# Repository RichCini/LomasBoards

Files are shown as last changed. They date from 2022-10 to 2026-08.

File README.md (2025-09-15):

# LomasBoards
Small repository of files/data related to Lomas Data Products S-100 boards. I have
a particular interest in the Color Magic video board as it seems to have been
supported by the Seattle Gazelle that I own. 

## Color Magic Redux 
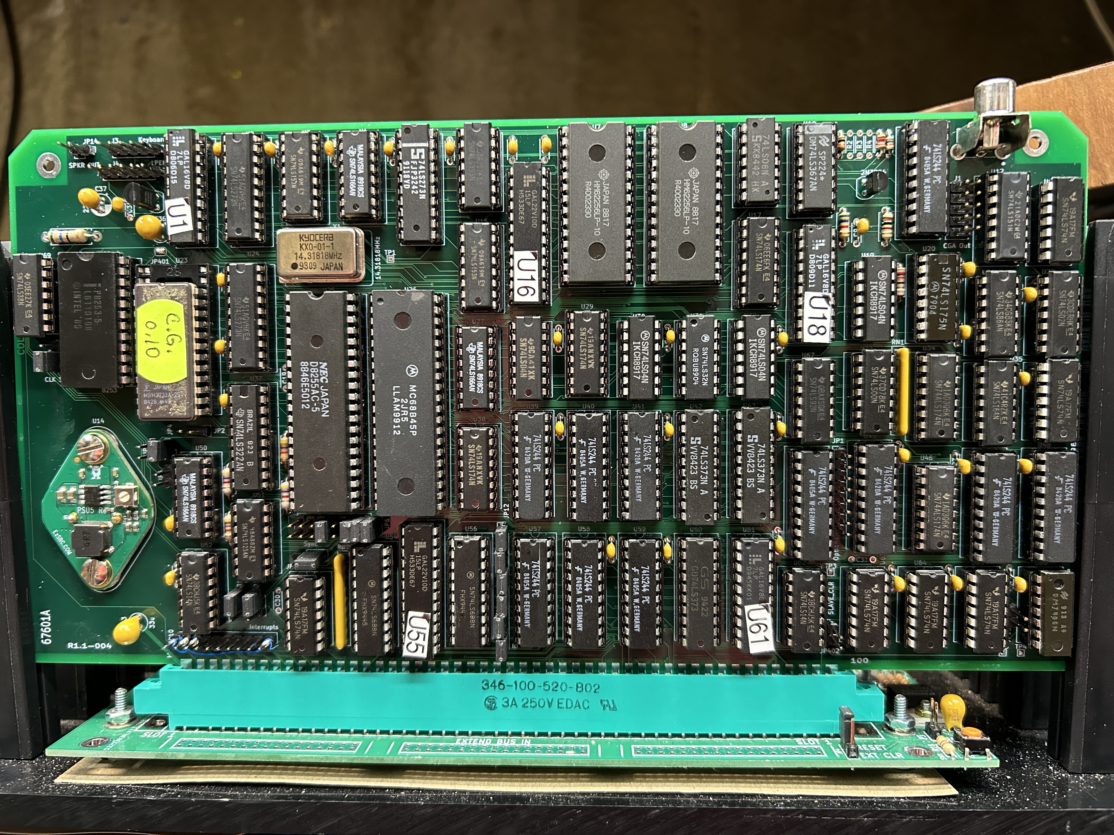
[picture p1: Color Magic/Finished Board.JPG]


### Status - version 1.1-005 / Version 006 In Development
1.1-005 is the release version, although in the process of debugging CGA Mode 6
(used for Windows 1.04 and Sim City) I discovered that the RAM chip selects are
improperly connected to MA13. It is OK to run the board without the following change if
only text or low-resolution modes are used.

To make the correction on existing 1.1-005 boards, it requires lifting pin 20
of each SRAM (CS*) and connecting it to ground, and lifting pin 26 (A13) and
connecting to MA13 (pin 20 of the socket). I did this with some 30AWG wire-
wrapping wire soldered to the tops of the pins in question.

There is also a revised versions of the U18 and U55 PALs that's recommended for all users.
Again, the update to U18 is related to discoveries made in debugging Mode 6, while the
update to U55 is related to a discovery by Patrick Linstruth that the MS-DOS RTC was
running fast. The 8253 timer was not being initialized properly due to a missing term
in one of the equations.

### Board Notes
Regarding CGA Mode 6, with the above change, it now works, although it shows a
screen artifact, the same as the original board. In this mode, there is a vertical
black stripe along the left side of the screen image which would indicate there's
a timing issue in the horizontal blanking (i.e., video out is being enabled 
one-half character time too early, before the load/shift from the character generator
is ready for the first set of dots, and then disabled the same half-character early
at the end of the video line.) As this exists in the original board, its a mode that
may have not been tested because so few software packages at the time used that mode.

The 5V voltage regulator is a TO-3 switching replacement from EzSBC. To preserve the
footprint and schematic symbol, it's shown as an LM7805K.

The speaker connection is like the PC -- simple 4-8 ohm speaker.

The keyboard is a standard PC 5150 type. If you want to use a PS/2-style 
keyboard, you need to use an AT2XT keyboard converter. I got mine on eBay
and it has both PS/2 and AT inputs and an XT (DIN-5) output. J3 is the
keyboard interface connector. You will need to build a small dongle cable 
with a DIN-5F on one end and a 1x5 0.1" pin header connector on the other.
The AT2XT adapter would then connect to this cable. The PC keyboard pinout
is available on the Internet.

Regarding video, the output is standard RGBI/CGA in addition to B&W composite. 
The RGBI interface cable is a standard 2x5 IDC to a DE9F. To use with a modern
HDMI monitor, you need to use an RGB2HDMI adapter like the one from TexElec
(https://texelec.com/product/rgbtohdmi-ttl/?highlight=hdmi). This one works
very well and can be used for more than just this setup.

Regarding memory devices, the design seems to be very sensitive to device speeds
(i.e. EPROM and SRAM). The character generator EPROM is a D2732A which is a 250ns
device. The original SRAM are stacked 6264-15 (150ns) chips which I replaced with
62256-10 (100ns) devices with some adjustments to the circuit. I temporarily used
55ns chips, and those resulted in screen artifacts. PAL device speeds are either
7ns or 15ns depending on the device.

## Thunder 186 Redux 
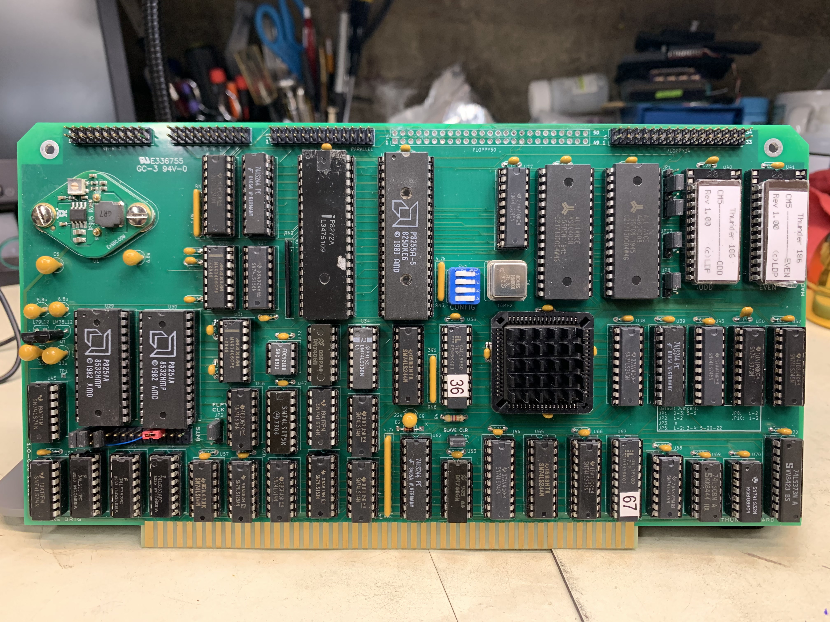
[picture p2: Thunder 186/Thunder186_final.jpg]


### Status - version 1.0-006 FINAL
Three minor changes: the serial headers were changed back to the 2x10 used on the prototype
(which then requires using a DB25F cable), consistent with the original; corrected the
footprint on C9 to a polarized tantalum; final change was to rotate the CPU 180 degrees
to have the chip legend oriented properly.

As with the ColorMagic, the 5V voltage regulator is a TO-3 switching replacement from EzSBC. 
To preserve the footprint and schematic symbol, it's shown as an LM7805K.

### Board Notes
The serial section seems to be sensivite to the voltage levels used on the interface of the
peripherals connected to it. This became evident when trying the old Move-IT file transfer
program. My go-to serial-USB dongle wasn't driving the handshaking lines to conforming
voltages. After changing USB interfaces, it worked. Original interfaces, like on a DOS
laptop I keep around for such purposes, work fine.

Regarding DOS versions, I run PC/DOS rather than MS-DOS. Versions 3.0, 3.1, and 3.3 work.
I have a single 360k MS-DOS 3.1 disk image which is posted. MS-DOS 2.1 disks are 
also in the archive, but appear to rely on direct calls into the monitor in order to
boot (non-standard MS-DOS boot sector) and are 320k in size (8 sectors).

The I/O ports (serial and parallel) are at non-standard, non-PC-compatible addresses, so
any software that uses them either has to (1) allow for defining custom ports, (2) read
the BIOS data area in order to get the right port number, or (3) rely solely on BIOS
calls to access the hardware. 

Similar to the serial port, the parallel port seems sensitive to what it's connected
to. I used LPT-Capture (https://github.com/bkw777/LPT_Capture) which works with an old
DOS laptop but will not work with this parallel port. I have gotten it working using a
Practical Peripherals Serial/Parallel converter/buffer. Although I haven't tested it,
it's possible the LPT-Capture would work on that port.

In the process of debugging Mode 6 video (mentioned above) some users reported that depending
on the S-100 backplane used, a pull-up resistor might be needed on PRDY (pin 72). There is a note
on the schematic about this, but the original design did not include one. RN2 pin 8 (1.0k 
resistor array) can be connected to pin 72 (on the rear) of the S-100 edge connector with a piece
of wirewrap wire.

### Status - version 1.0-005 Working
Works! PC-DOS 3 reports 256k of RAM which is correct. 

There is one errata. Capacitor C9 in the reset circuit should be 22uF/16v polarized; it
is misdrawn on the original schematic. A regular tantalum fits fine in this space. The
original board uses a 10v tantalum.

## LomasSCSI 

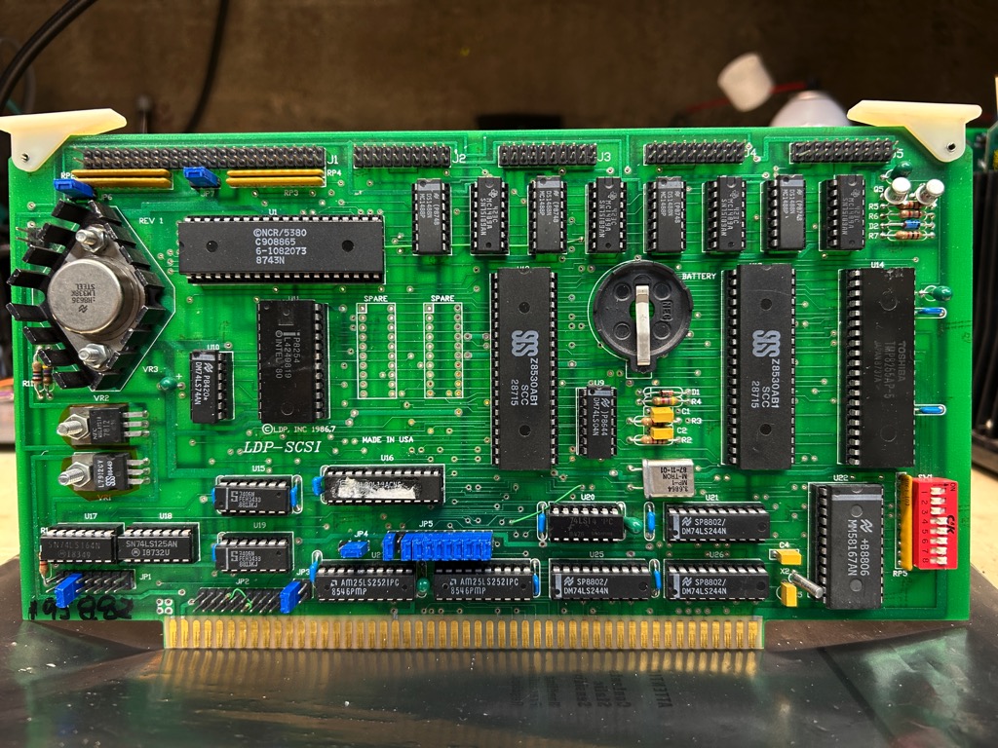
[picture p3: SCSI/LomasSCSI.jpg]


### Status --
The board is about 85% redrawn in KiCAD. Since no printed schematics are known to exist, this is
being done by the "continuity tester" method -- ohming out every connection on the board. Slow
going at best. This method did allow me to determine the PAL pin usage, though.

The board contains one PAL, U16 (a 20L10), used as an address decoder. The PAL has been reversed and the
equations tested against the original by burning another PAL, but without a working test setup for
the original board, confirming that the equations are 100% correct is difficult. From probing,
I do believe that they are correct, though. So, more to come on this.

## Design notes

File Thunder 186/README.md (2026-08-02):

# Thunder 186
Small repository of files/data related to Lomas Data Products Thunder 186 as well
as the KiCAD design files for my replica.

## Disk Images
From a Facebook purchase, I was able to obtain original MS-DOS 2.11 and
Concurrent CP/M-86 distribution disks. The MS-DOS disks were intact and
readable but they will not mount on any normal system because the format
of track 0 is unique to Lomas. Patching it to make it readable in a
normal machine makes it unusable on the T186 (you need to overwrite
sector 0 with a standard MS-DOS boot sector).

Regarding the Concurrent CP/M-86 disks, disk 1 is not readable due to a
destroyed directory. Disks 2 and 3 are fine. Pete Higgins did extract 
the files from each disk and those are posted. Online AI tools did
grind away at the image and repaired it enough, but some of the programs
need to be replaced, and it's still not bootable. Progress...

The PCDOS-winslow disk is a PC/DOS bootable image that contains
Windows 1.0 configured for no mouse and a CGA monitor. It will work
with the ColorMagic, but the user experience is bad without a mouse.

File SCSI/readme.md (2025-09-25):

Unfortunately not a lot is known about this board from Lomas. It's a SCSI controller with two serial ports and an RTC.
Schematics are not known to exist, and I have not been able to locate a manual anywhere. The onboard ROM has been 
archived, but it contains a PAL which is more difficult to de-logic without a schematic. Using the DuPAL tool and
some manual logic texting, I think the equations posted are very close to actual, but without a working setup
(in process), it's hard to test.

The schematics, board plot, and design files are as close to actual that I can get without seeing an original
schematic. I ohmed-out the entire board, so I'm pretty confident its right, but still...

I made one component substitution which saved three chips -- I used higher-density MAX1406 level shifters rather
than the usual MC1488/MC1489. Other than that, it's all the same.

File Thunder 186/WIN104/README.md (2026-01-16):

# Notes on Windows 1.04 on Lomas Boards

## Introduction
The Thunder 186 and its BIOS are kind-of PC-Compatible in the way that
the Tandy 2000 was PC-Compatible. So long as software uses either MS-DOS
INT21h calls or direct BIOS calls, it should work fine. Anything else
would require writing custom hardware interfaces because device port 
addresses are at non-standard locations.

The Tandy 2000 was able to run Windows 1.04 using OEM drivers written
by Tandy (or someone contracted by Tandy). Since the Color Magic is
CGA-compatible, the other hardware items which would need custom
drivers would be for the serial and parallel ports, and the "system"
itself (which means floppy drive configuration and system timers).

No copies of the Tandy driver sources are known to exist, but the 
pre-install disk does exist. No copies of an "OEM Adaptation Kit"
are known to exist for Windows 1, but there is one for Windows 2
(which unfortunately is different enough). So, I've attempted to
back-port the published sources for COMM and SYSTEM from Windows 2.03
to something that would work for Windows 1, using a decompilation of 
the Tandy drivers as a guide.

## Status
As of now, I've back-ported SYSTEM and at least it doesn't crash. I'm
not sure if it's right, but no crashing is good.

I'm in the process of back-porting of COMM but that's much tougher
because the interrupt system in the Thunder 186 is all different
(and even different from the Tandy 2000). I'd love to locate a
"null" COMM driver and use that for now.

Windows will load and run using the "slow boot" configuration
and the CGA video driver (DRV, GRB, and LGO files) and it does work. 

Windows 1 and 2 used a monolithic file containing all of the drivers
combined in one file to improve loading performance. The modern analog 
would be the WIN386 file in Windows 3.1 where all of the VXDs are combined. 
The slow boot configuration is a special debug mode using the debug
kernel and the individual drivers for COMM, DISPLAY, KEYBOARD, MSDOS, MOUSE, 
and SOUND. It facilitated debugging and swapping drivers for testing.

There is a screen anomaly where it appears that the screen is shifted right 
by half a character cell. It's the same with the original Color Magic and the
one I re-created, so it's not a "board thing" but something in the video
subsystem and/or BIOS where the blanking signal is delayed slightly too long. 
I played around with delays in the video circuit but I was never able to get it
to be perfect, so I just left it. It's not clear whether Lomas envisioned
being able to run Windows, so they either never tested, or didn't care to
fix it.

Also, there is no mouse input. Mouse input relies on either standard
serial ports or an InPort bus mouse, neither of which is straightforward
to implement on a Lomas system because of the interrupt system. It would
require a redesign of the interrupt system to use external 8259 PICs 
instead of the PIC internal to the 80186. On the up side, keyboard
shortcuts work.

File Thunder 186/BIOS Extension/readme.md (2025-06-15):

Note that due to the age of the code, a relatively primative version of Microsoft MACRO assembler is needed.
The build files came from the zip file located as a link at https://www.os2museum.com/wp/dos-2-11-from-scratch/

MASM and EXE2BIN are dated 2/1/83 and LINK is dated 1/6/83.

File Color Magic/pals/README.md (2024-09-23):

# Reading the PALs
Although I'm keeling the summary below, it turned out that the PALs were not able to
be decoded properly using the method below. It required the assistance of someone
with more robust hardware and an intimate knowledge of PAL equation writing. He was
able to reverse the PALs and produce working files. I plan on trying to replicate
his setup at some point, but that's to come.

## DuPAL board
The basis of reading the PALs is a project called DuPAL (https://github.com/DuPAL-PAL-DUmper)
which has several associated Java-based tools to read the PAL, analyze the results,
and do equation reductions. The instructions aren't as fulsome as they could be, 
so here are some notes to hopefully make it easier for others. Also helpful is the site
https://proghq.org/wiki/index.php/DuPAL which runs through compiling some of the Java
code.

Largely no issues getting the board manufactured. Rather than using the existing gerbers,
I loaded the design into KiCAD and tweaked a few components and placements to fit my
liking. I moved the overlapped bypass capacitors and changed the foortprints for the
DE9M, power switch, and the coaxial power jack to match parts I already had in-stock.

## DuPAL Firmware
The Atmel ATMega328 can be programmed in-circuit using the ISP header (for loading
the Optiboot bootloader) or out-of-circuit using any number of methods. I used a
USBtinyISP programmer from Adafruit attached to the ISP header. First, download Optiboot, 
compile it, and the program it into the ATMega:

  make atmega328 AVR_FREQ=20000000L LED_START_FLASHES=8 BAUD_RATE=57600

  avrdude  -c avrtiny -P /dev/ttyUSB0 -p atmega328p -e -u -U efuse:w:0xFD:m \
  -U hfuse:w:0xDE:m -U lfuse:w:0xFF:m -U flash:w:optiboot_atmega328.hex

Connect the host PC to the serial port on the DuPAL, compile and upload the firmware:

  make

  make program

## DuPAL Analyze
The different software packages require different versions of Java. Analyze uses Java 8.
Make sure that "maven" is installed: 

  sudo apt-get install maven

Then, change to the directory with the source code and compile it:

  mvn compile

  sudo mvn install

The ./target folder contains the compiled JAR file. Run that:

  java -jar ./target/dupal-analyzer-0.1.4-jar-with-dependencies.jar /dev/ttyUSB0 16L8 out.json

It will first analyze the GAL to detect the byte mask. Then, re-run with the detected mask (where "xx"
is the mask number provided):

  java -jar ./target/dupal-analyzer-0.1.4-jar-with-dependencies.jar /dev/ttyUSB0 16L8 out.json xx

## DuPAL Peeper
This program requires compiling using Java 11, so you need to switch to that before
compiling.

Using in on-line mode:

  java -jar ./target/dupal-peeper-0.0.1-jar-with-dependencies.jar --serial=/dev/ttyUSB0 --pal=16L8

Using in off-line mode:

  java -jar ./target/dupal-peeper-0.0.1-jar-with-dependencies.jar --dump=/path/to/dump.json

## DuPAL Espresso Converter
This program requires compiling using Java 11, so you need to switch to that before
compiling. I have not played with this yet, but here's the command line:

  java -jar espresso_converter.jar <input_file> <output_file> [single output table] [use only source FIOs Y|N]

  java -jar ./target/espresso-converter-0.0.3-jar-with-dependencies.jar

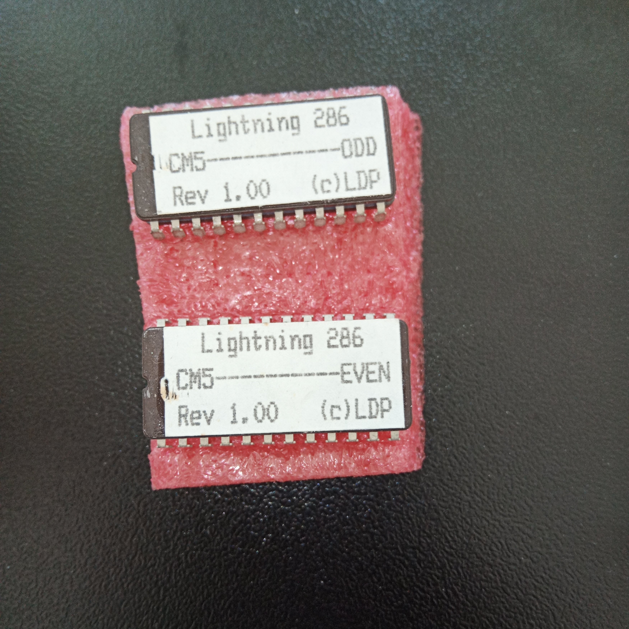
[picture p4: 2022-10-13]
ROMs.jpg

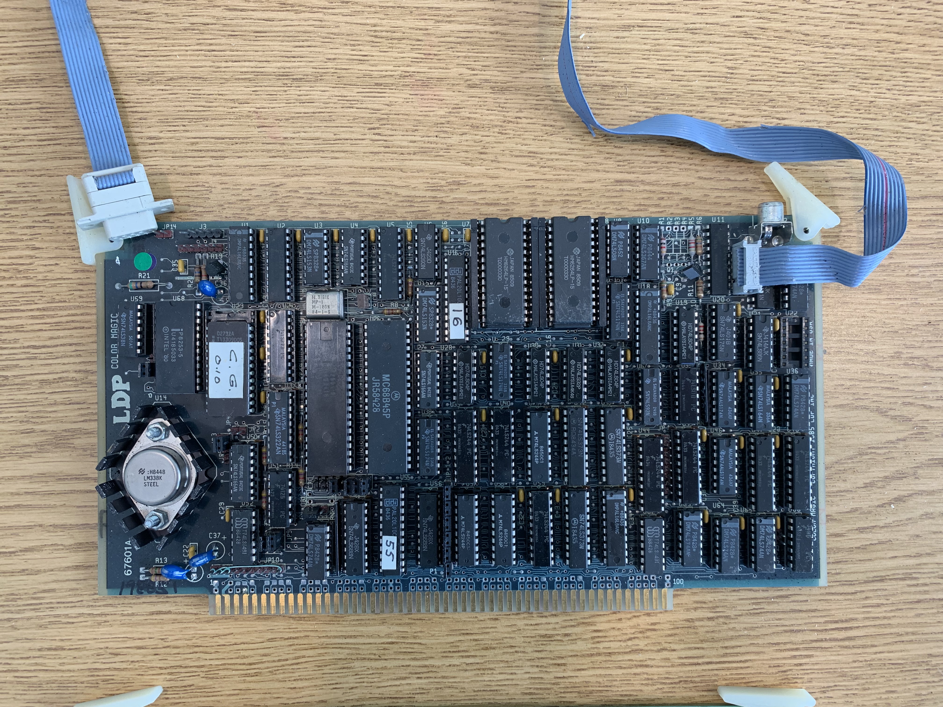
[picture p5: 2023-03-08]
Color Magic/Lomas_ColorMagic_Video.jpg

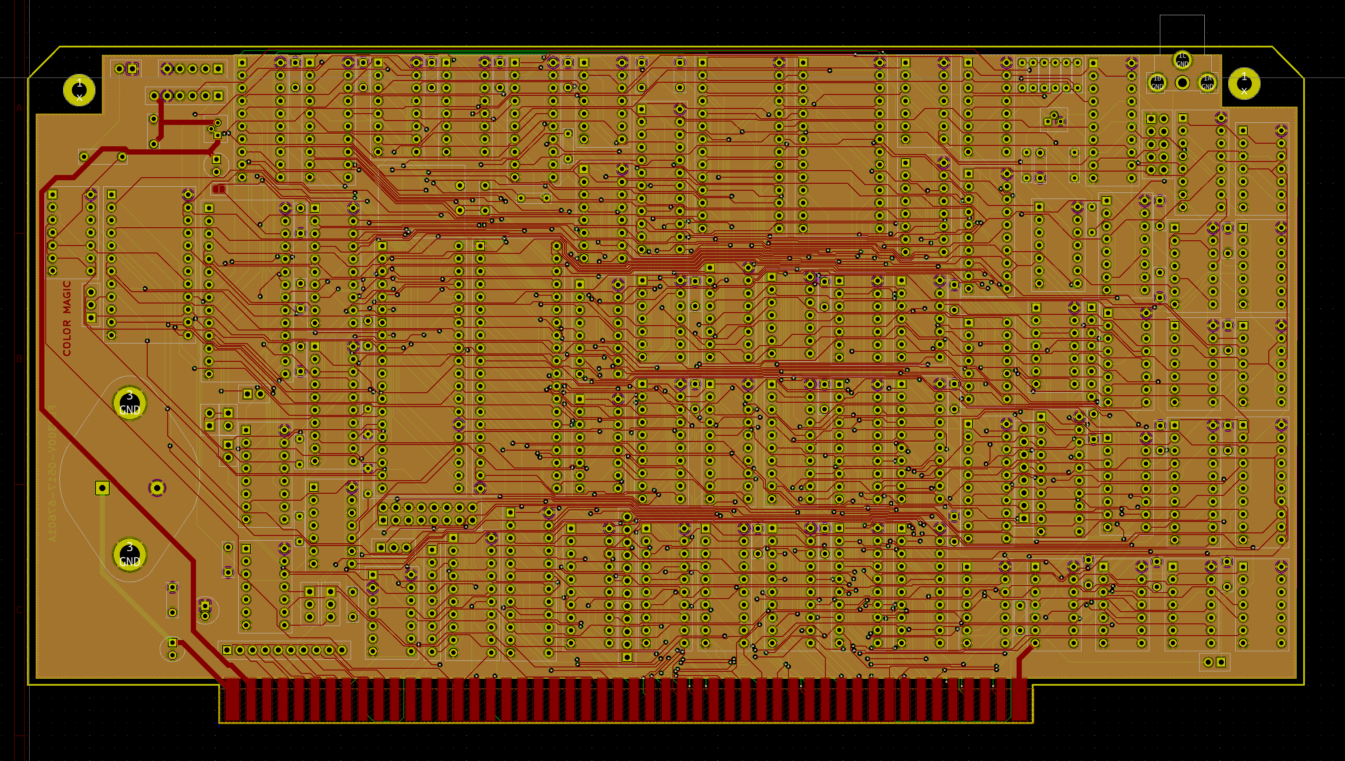
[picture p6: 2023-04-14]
Color Magic/Screen Shot 2023-04-14 at 8.41.56 AM.png

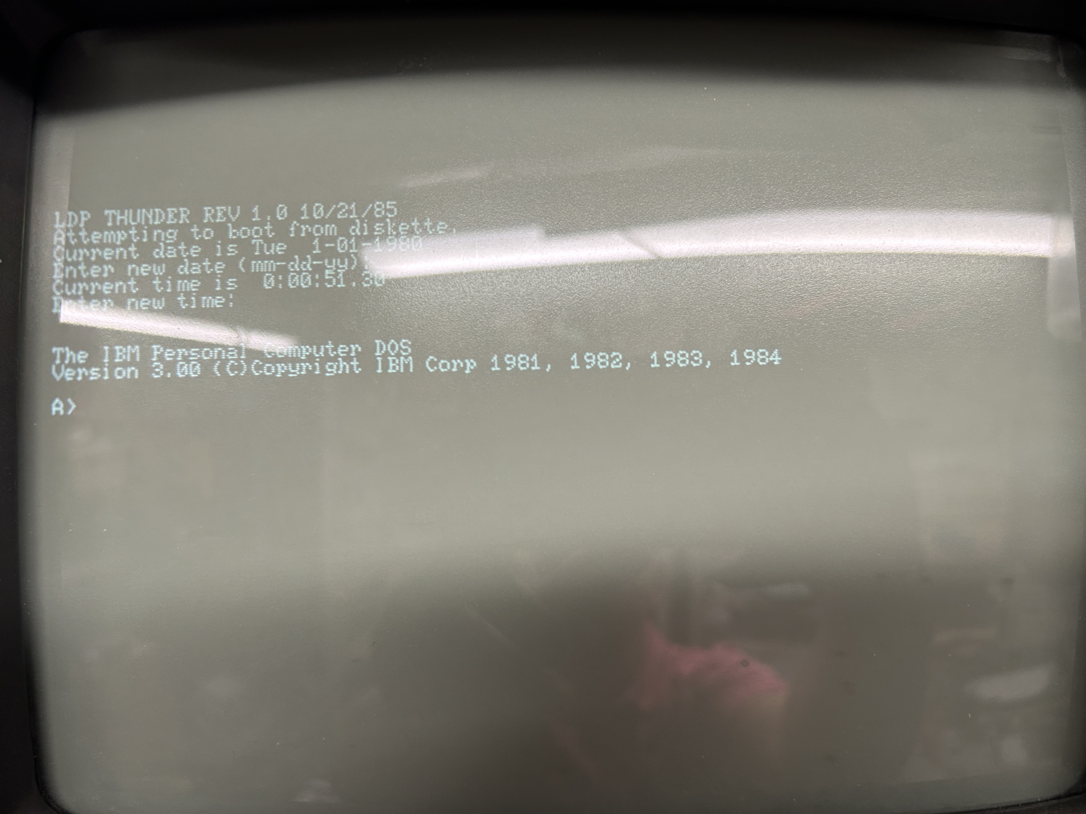
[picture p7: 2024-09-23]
Color Magic/LCM_first_working.JPG

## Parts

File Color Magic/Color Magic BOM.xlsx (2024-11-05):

Schematic Part # | Description | Total quantity of this part | Part Number | Source
C1, C2, C3, C4, C5, C6, C7, C9, C10, C11, C12, C14, C15, C16, C17, C20, C21, C18, C19, C20, C21, C22, C23, C24, C25, C26, C27, C28, C29, C30, C31,C32, C33, C34, C35, C38, C39, C40 | 0.1 uF, 50 Volt, Monolithic, X7R, Radial | 38 | 544921 | Jameco
C13, C36 | 33 uF, 25 Volt, 10%, Radial Tantalum | 2 | 33785 | Jameco
C19, C30, C31 | 47pF, 50V Monolithic Radial 2.5mm lead | 3 | 81-RDE5C1H470J0M1H3A | Mouser
C37 | 22uF, 35V, 10%, Radial Tantalum | 1 | 2040196 | Jameco
J1 (RGBI video out) | 5x2 Position, Unshrouded Header 2.54mm Solder, Straight | 1 |  | Jameco
J2 (Composite video out) | RCA jack, right angle PC mount | 1 | 220564 | Jameco
J3 (Keyboard) | 5 Position, Unshrouded Header 2.54mm Solder Straight | 1 |  | Jameco
J4 (Light pen) | 6 Position, Unshrouded Header 2.54mm Solder Straight | 1 |  | Jameco
JP2, JP3, JP4, JP5, JP14, JP15, JP402 | 2 Position, Unshrouded Header 2.54mm Solder Straight | 7 |  | Jameco
JP6 | 8x2 Position, Unshrouded Header 2.54mm Solder, Straight | 1 |  | Jameco
JP7, JP8, JP9. JP13 | 3 Position, Unshrouded Header 2.54mm Solder Straight | 4 |  | Jameco
JP10 | 10 Position, Unshrouded Header 2.54mm Solder Straight | 1 |  | Jameco
JP12 | 12 Position, Unshrouded Header 2.54mm Solder Straight | 1 |  | Jameco
JP401 | solder bridge
U1 | GAL16V8D 7LP or 7LPN | 20 | GAL16V8D 7LPN | utsource.net
U2 | 74LS273 | 20 | 595-SN74LS273N | Mouser
U3 | 74LS153 | 16 | 595-SN74LS153N | Mouser
U4 | 74LS166 | 16 | 595-SN74LS166AN (https://www.mouser.ca/ProductDetail/595-SN74LS166AN) | Mouser
U5 | 74LS273 | 20 | 595-SN74LS273N | Mouser
U6 | 74LS393 | 14 | 595-SN74LS393N | Mouser
U7 | HM62256LP-10 | 28 | HM62256LP-10 | utsource.net
U8 | HM62256LP-10 | 28 | HM62256LP-10 | utsource.net
U9 | 74LS08 | 14 | 595-SN74LS08N (https://www.mouser.ca/ProductDetail/595-SN74LS08N) | Mouser
U10 | 74LS367 | 16 | 595-SN74LS367AN | Mouser
U11 | 74LS244 | 20 | 595-SN74LS244N | Mouser
U12 | 74LS151 | 16 | 595-SN74LS151N | Mouser
U13 | 74LS74 | 14 | 595-SN74LS74AN (https://www.mouser.ca/ProductDetail/595-SN74LS74AN) | Mouser
U14 | EzSBC PSU5 5V switching regulator |  | PSU5 | ezsbc.shop
U15 | 74LS153 | 16 | 595-SN74LS153N (https://www.mouser.ca/ProductDetail/595-SN74LS153N) | Mouser
U16 | GAL22V10D 15LP | 24 | GAL22V10D 15LP | utsource.net
U17 | 74LS174 | 16 | 595-SN74LS174N (https://www.mouser.ca/ProductDetail/595-SN74LS174N) | Mouser
U18 | GAL16V8D 7LP or 7LPN | 20 | GAL16V8D 7LPN | utsource.net
U19 | 74LS04 | 14 | 595-SN74LS04N (https://www.mouser.ca/ProductDetail/595-SN74LS04N) | Mouser
U20 | 74LS175 | 16 | 595-SN74LS175N | Mouser
U21 | 74LS86 | 14 | 595-SN74LS86AN | Mouser
U22 | 74LS02 | 14 | 595-SN74LS02N | Mouser
U23 | Fujitsu MBM2732A-25 EPROM | 28 | MBM2732A-25 | utsource.net
U24 | 74LS273 | 20 | 595-SN74LS273N | Mouser
U25 | 8255AC-5 peripheral interface | 40 | 8255AC-5 | utsource.net
U26 | MC68B45P display controller | 40 | MC68B45P | utsource.net
U27 | 74LS166 | 16 | 595-SN74LS166AN | Mouser
U28 | 74LS04 | 14 | 595-SN74LS04N (https://www.mouser.ca/ProductDetail/595-SN74LS04N) | Mouser
U29 | 74LS174 | 16 | 595-SN74LS174N (https://www.mouser.ca/ProductDetail/595-SN74LS174N) | Mouser
U30 | 74LS04 | 14 | 595-SN74LS04N (https://www.mouser.ca/ProductDetail/595-SN74LS04N) | Mouser
U31 | 74LS32 | 14 | 595-SN74LS32N | Mouser
U32 | 74LS04 | 14 | 595-SN74LS04N (https://www.mouser.ca/ProductDetail/595-SN74LS04N) | Mouser
U33 | 74LS00 | 14 | 595-SN74LS00N (https://www.mouser.ca/ProductDetail/595-SN74LS00N) | Mouser
U34 | 74ALS174 | 16 | 595-SN74ALS174N (https://www.mouser.ca/ProductDetail/595-SN74LS174N) | Mouser
U35 | 74LS164 | 14 | 595-SN74LS164N (https://www.mouser.ca/ProductDetail/595-SN74LS164N) | Mouser
U36 | 74LS74 | 14 | 595-SN74LS74AN (https://www.mouser.ca/ProductDetail/595-SN74LS74AN) | Mouser
U37 | 74LS322 | 20 | SN74LS322AN | utsource.net
U38 | 74LS174 | 16 | 595-SN74LS174N | Mouser
U39 | 74LS244 | 20 | 595-SN74LS244N | Mouser
U40 | 74LS244 | 20 | 595-SN74LS244N | Mouser
U41 | 74LS244 | 20 | 595-SN74LS244N | Mouser
U42 | 74LS373 | 20 | 595-SN74LS373N | Mouser
U43 | 74LS373 | 20 | 595-SN74LS373N | Mouser
U44 | 74LS244 | 20 | 595-SN74LS244N | Mouser
U45 | 74LS244 | 20 | 595-SN74LS244N | Mouser
U46 | 74ALS174 | 16 | 595-SN74ALS174N | Mouser
U47 | 74LS244 | 20 | 595-SN74LS244N | Mouser
U48 | 74LS244 | 20 | 595-SN74LS244N | Mouser
U49 | LM78L12 positive 12V .1A regulator |  | 595-UA78L12ACLPR | Mouser
U50 | 74LS166 | 16 | 595-SN74LS166AN (https://www.mouser.ca/ProductDetail/595-SN74LS166AN) | Mouser
U51 | 74125 or 74LS125 | 14 | SN74125N | utsource.net (for 74125)
U52 | 74LS14 | 14 | 595-SN74LS14N (https://www.mouser.ca/ProductDetail/595-SN74LS14N) | Mouser
U53 | 74LS74 | 14 | 595-SN74LS74AN (https://www.mouser.ca/ProductDetail/595-SN74LS74AN) | Mouser
U54 | 74LS688 | 20 | 595-SN74LS688N | Mouser
U55 | GAL22V10D 15LP | 24 | GAL22V10D 15LP | utsource.net
U56 | 74LS688 | 20 | 595-SN74LS688N | Mouser
U57 | 74LS244 | 20 | 595-SN74LS244N | Mouser
U58 | 74LS244 | 20 | 595-SN74LS244N | Mouser
U59 | 74LS244 | 20 | 595-SN74LS244N | Mouser
U60 | 74LS373 | 20 | 595-SN74LS373N | Mouser
U61 | GAL16V8D 7LP or 7LPN | 20 | GAL16V8D 7LPN | utsource.net
U62 | 74LS14 | 14 | 595-SN74LS14N (https://www.mouser.ca/ProductDetail/595-SN74LS14N) | Mouser
U63 | 74LS74 | 14 | 595-SN74LS74AN (https://www.mouser.ca/ProductDetail/595-SN74LS74AN) | Mouser
U64 | 74LS74 | 14 | 595-SN74LS74AN (https://www.mouser.ca/ProductDetail/595-SN74LS74AN) | Mouser
U65 | 74LS74 | 14 | 595-SN74LS74AN (https://www.mouser.ca/ProductDetail/595-SN74LS74AN) | Mouser
U66 | 7406 or 74LS06 | 14 | DN7406N | utsource.net (or 7406)
U67 | 74LS92 | 14 | 595-SN74LS92N | Mouser
U68 | 8253-5 interval timer | 24 | P8253-5 | utsource.net
U69 | 74LS38 | 14 | 595-SN74LS38N (https://www.mouser.ca/ProductDetail/595-SN74LS38N) | Mouser
RN1 | 4.7K x 7 SIP (8 pin) | 1 | 652-4608X-1LF-4.7K | Mouser
RN2 | 4.7K x 8 SIP (9 pin) | 1 | 652-4609X-1LF-4.7K | Mouser
R1 | 1.0K ohm 1/4W (1/8 body size) | 1 | 594-5063JD1K000F | Mouser
R2 | Not populated | 0
R3 | Not populated | 0
R4 | Not populated | 0
R5 | 2.2K ohm 1/4W (1/8 body size) | 1 | 594-5063JD2K200F | Mouser
R6 | 5.6K ohm 1/4W (1/8 body size) | 1 | 594-5063JD5K600F | Mouser
R9 | 5.6K ohm 1/4W | 1 | 660-MF1/4LCT52R562J | Mouser
R10 | 22 ohm 1/4W | 1 | 660-MF1/4LCT52R220J | Mouser
R11 | 100 ohm 1/4W | 1 | 660-MF1/4LCT52R101J | Mouser
R14, R15, R16, R17 | 4.7K ohm 1/4W | 4 | 660-MF1/4LCT52R472J | Mouser
R21 | 56 ohm 1/2W | 1 | 756-MFR4-56RFI | Mouser
Q1 | 2N3904 | 1 | 38359 | Jameco
X1 | 14.31818MHZ oscillator | 1 | 520-TCF1431-X | Mouser
14 pin socket 0.3 wide |  | 23
16 oinsocket 0.3 wide |  | 13
20 pin socket 0.3 wide |  | 23
24 pin socket 0.3 wide |  | 2
24 socket 0.6 wide |  | 1
28 socket 0.6 wide |  | 3
40 socket 0.6 wide |  | 2
CGA monitor cable |  | 1 | Use standard IDC10 to DE9F
Keyboard cable |  | 1 | See board notes

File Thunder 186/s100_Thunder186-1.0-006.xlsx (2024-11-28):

Have? | Reference | Value | Qty | Part_Number | Footprint
 | C1,C2,C3 | 6.8u, 35v | 3 |  | Capacitor_THT:CP_Radial_Tantal_D4.5mm_P2.50mm
 | C4,C5,C10,C11,C12,C13,C14,C15,C16,C17,C18,C19,C20,C21,C22,C23,C24,C25,C26,C27,C28,C29,C30,C31,C32,C33,C34,C35,C36,C37,C38,C39,C40,C41,C42 | 0.1 uF, 50v | 35 |  | Capacitor_THT:C_Disc_D4.3mm_W1.9mm_P5.00mm
 | C6,C7,C8 | 33u, 25v | 3 |  | Capacitor_THT:CP_Radial_Tantal_D4.5mm_P2.50mm
 | C9 | 22u, 16v | 1 |  | Capacitor_THT:CP_Radial_Tantal_D4.5mm_P2.50mm
 | D2 | 1N4148 | 1 |  | Diode_THT:D_DO-35_SOD27_P7.62mm_Horizontal
 | J1, J2 | Header 2x5 | 2 |  | Connector_PinHeader_2.54mm:PinHeader_2x05_P2.54mm_Vertical
 | J3 | Header 2x13 | 1 |  | Connector_PinHeader_2.54mm:PinHeader_2x13_P2.54mm_Vertical
 | J4 | Header 2x17 | 1 |  | Connector_PinHeader_2.54mm:PinHeader_2x17_P2.54mm_Vertical
 | J5 | Header 2x25 | 1 |  | Connector_PinHeader_2.54mm:PinHeader_2x25_P2.54mm_Vertical
 | JP1 | Header 1x6 | 1 |  | Connector_PinHeader_2.54mm:PinHeader_1x06_P2.54mm_Vertical
 | JP2 | Header 1x3 | 1 |  | Connector_PinHeader_2.54mm:PinHeader_1x03_P2.54mm_Vertical
 | JP3 | Header 1x2 | 1 |  | Connector_PinHeader_2.54mm:PinHeader_1x02_P2.54mm_Vertical
 | JP5 | Header 2x14 | 1 |  | Connector_PinHeader_2.54mm:PinHeader_2x14_P2.54mm_Vertical
 | Q1 | LM78L12 | 1 |  | Package_TO_SOT_THT:TO-92L
 | Q2 | L79L12 | 1 |  | Package_TO_SOT_THT:TO-92L
 | R4 | 4.7kQ | 1 |  | Resistor_THT:R_Axial_DIN0207_L6.3mm_D2.5mm_P7.62mm_Horizontal
 | RN1 | 1.0k Rpack R5 SIP6 | 1
 | RN2 | 1.0k Rpack R9 SIP10 | 1
 | RN3 | 4.7k Rpack R4 SIP5 | 1
 | RN4 | 4.7k Rpack R9 SIP10 | 1
 | RN6 | 390 ohm Rpack R5 SIP6 | 1
 | SW1 | DIPSW_4 | 1 |  | Package_DIP:DIP-8_W7.62mm_Socket
 | U1 | LM7805K | 1 |  | Package_TO_SOT_THT:TO-3
 | U17 | 74LS156 | 1 |  | Package_DIP:DIP-16_W7.62mm_Socket
 | U2 | 74LS240 | 1 |  | Package_DIP:DIP-20_W7.62mm_Socket
 | U27,U38,U43,U52,U64 | 74LS245 | 5 |  | Package_DIP:DIP-20_W7.62mm_Socket
 | U28,U31 | MAX1406CPE+ | 2 |  | Package_DIP:DIP-16_W7.62mm_Socket
 | U29,U30 | 8251A | 2 |  | Package_DIP:DIP-28_W15.24mm_Socket
 | U3,U35,U39,U62,U65 | 74LS244 | 5 |  | Package_DIP:DIP-20_W7.62mm_Socket
 | U32 | FDC9216 | 1 |  | Package_DIP:DIP-8_W7.62mm_Socket
 | U33,U63 | 7406 | 2 |  | Package_DIP:DIP-14_W7.62mm_Socket
 | U34 | 74LS138 | 1 |  | Package_DIP:DIP-16_W7.62mm_Socket
 | U36,U67 | PAL16L8 | 2 |  | Package_DIP:DIP-20_W7.62mm_Socket
 | U37 | 80186 | 1 |  | Package_LCC:PLCC-68_THT-Socket
 | U4 | 8272A | 1 |  | Package_DIP:DIP-40_W15.24mm_Socket
 | U40,U41 | 27256 EPROM | 2 |  | Package_DIP:DIP-28_W15.24mm
 | U44,U51 | AS6C4008-55PCN | 2 |  | Package_DIP:DIP-32_W15.24mm
 | U45,U48,U53 | 74LS74 | 3 |  | Package_DIP:DIP-14_W7.62mm_Socket
 | U46 | 74LS06 | 1 |  | Package_DIP:DIP-14_W7.62mm_Socket
 | U47 | 74LS175 | 1 |  | Package_DIP:DIP-16_W7.62mm_Socket
 | U49,U59,U61 | 74LS14 | 3 |  | Package_DIP:DIP-14_W7.62mm_Socket
 | U5 | 82C55A | 1 |  | Package_DIP:DIP-40_W15.24mm
 | U50,U66,U72 | 74LS373 | 3 |  | Package_DIP:DIP-20_W7.62mm_Socket
 | U54,U55 | 74LS157 | 2 |  | Package_DIP:DIP-16_W7.62mm_Socket
 | U56 | 74LS161 | 1 |  | Package_DIP:DIP-16_W7.62mm_Socket
 | U57 | 74LS04 | 1 |  | Package_DIP:DIP-14_W7.62mm_Socket
 | U58 | 74LS125 | 1 |  | Package_DIP:DIP-14_W7.62mm_Socket
 | U60 | 74LS153 | 1 |  | Package_DIP:DIP-16_W7.62mm_Socket
 | U68 | 74LS375 | 1 |  | Package_DIP:DIP-16_W7.62mm_Socket
 | U69 | 74LS08 | 1 |  | Package_DIP:DIP-14_W7.62mm_Socket
 | U70 | 74LS32 | 1 |  | Package_DIP:DIP-14_W7.62mm_Socket
 | X1 | 16MHz Oscillator DIP-8 | 1 |  | Oscillator:Oscillator_DIP-8
 | Socket | DIP8-Osc | 1
 | Socket | DIP8 | 1
 | Socket | DIP14 | 13
 | Socket | DIP16 | 10
 | Socket | DIP20 | 16
 | Socket | DIP28 | 4
 | Socket | DIP32 | 2
 | Socket | DIP40 | 2
 | Socket | PLCC68 | 1

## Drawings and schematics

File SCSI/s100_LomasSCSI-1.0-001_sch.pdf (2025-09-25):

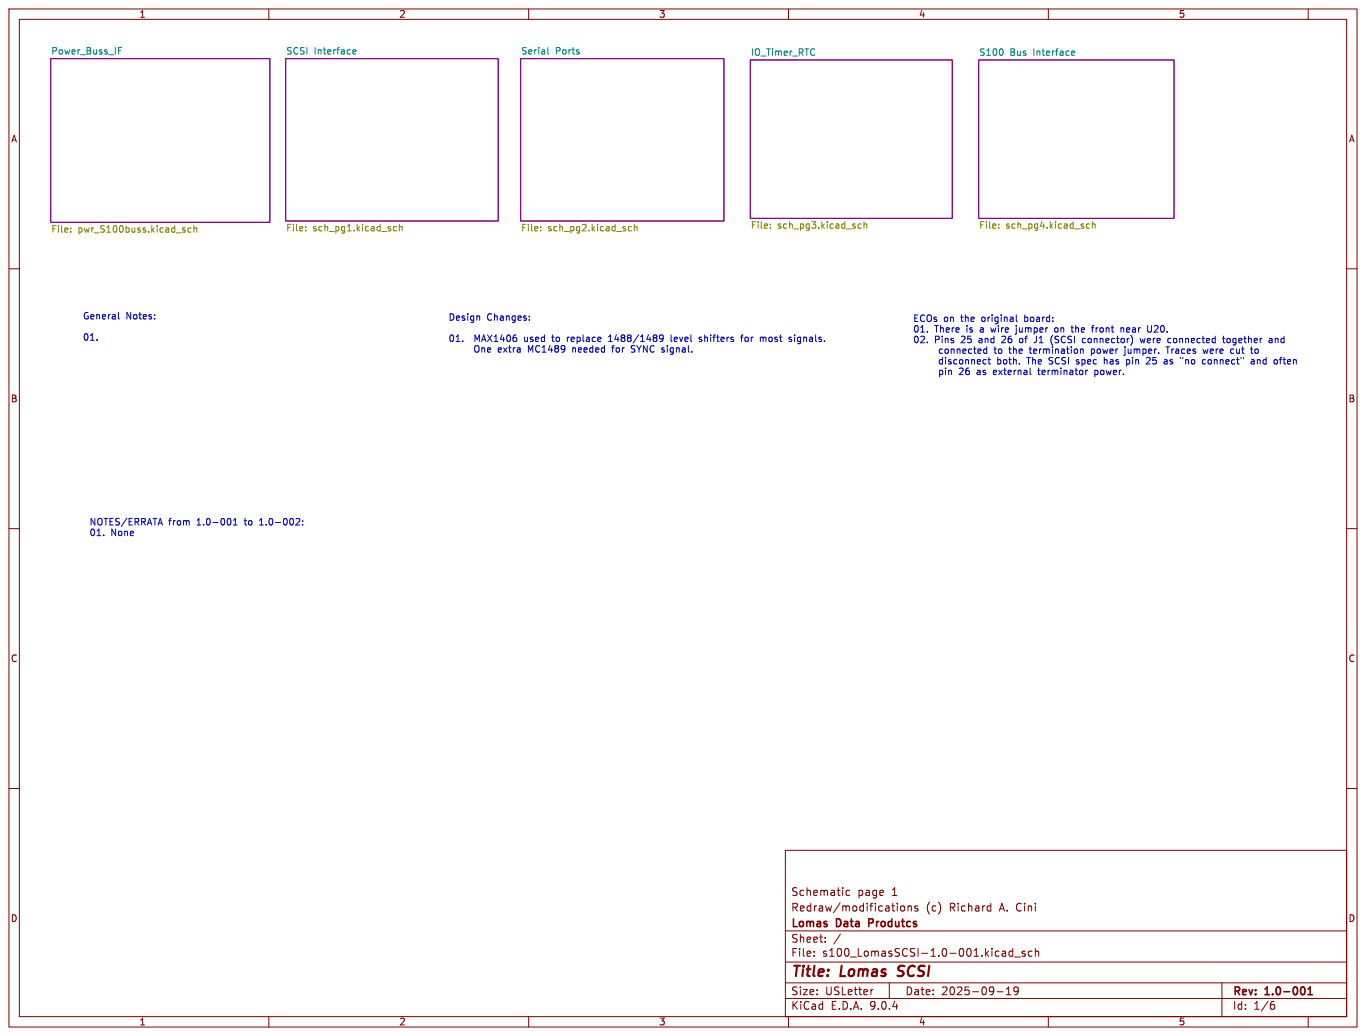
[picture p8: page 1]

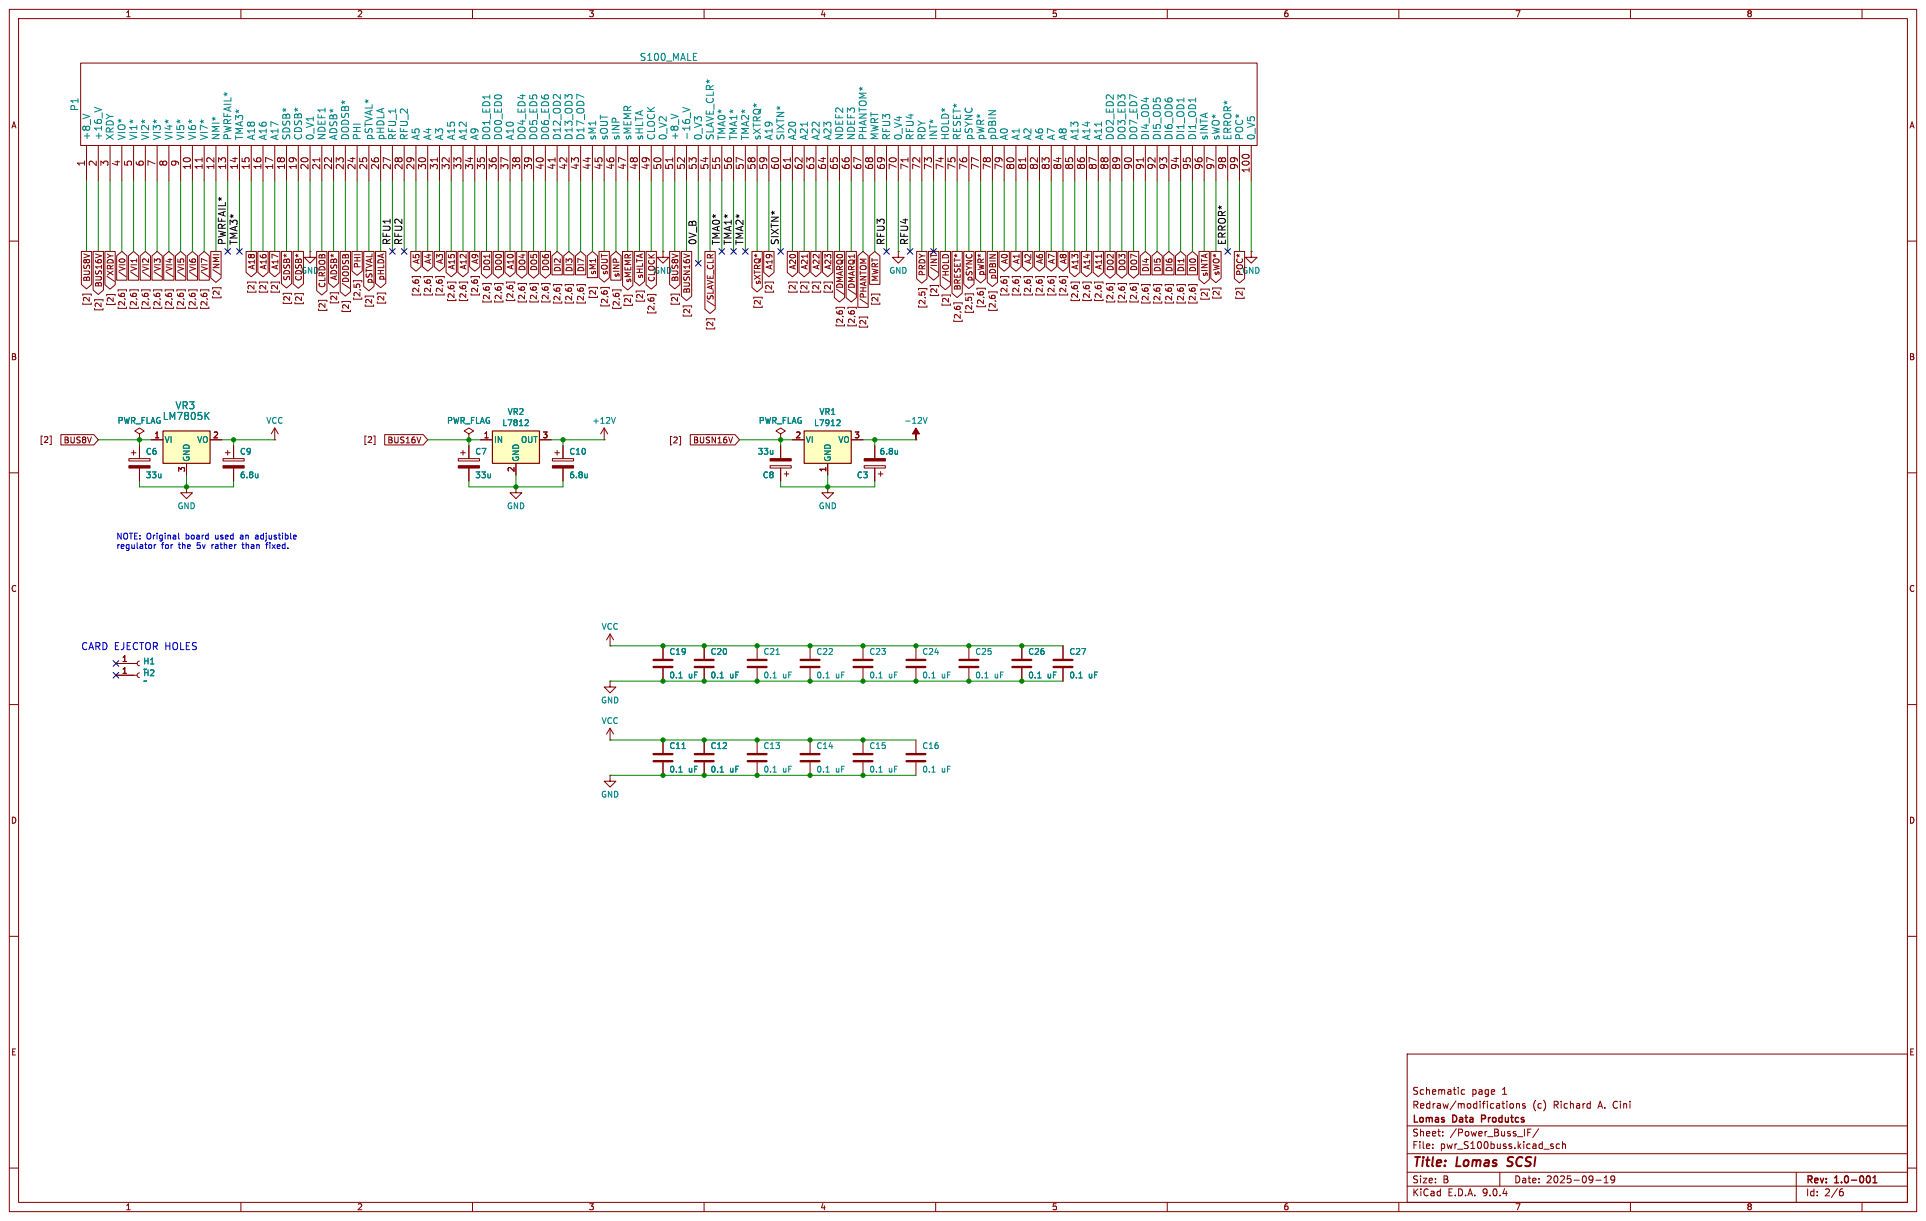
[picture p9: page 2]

3 VIO* 4 VI1* 5 VI2* 6 VI3* 7 VI4* 8 VI5* 9 VI6* 10 VI7* 11 NMI* 12 PWRFAIL* 13 TMA3* 14 A18 15 A16 16 A17 17 SDSB* 18 CDSB* 19 0_V1 20 NDEF1 21 ADSB* 22 DODSB* 23 PHI 24 pSTVAL* 25 pHDLA 26 RFU_1 27 RFU_2 28 A5 29 A4 30 A3 31 A15 32 A12 33 A9 34 DO1_ED1 35 DO0_ED0 36 A10 37 DO4_ED4 38 DO5_ED5 39 DO6_ED6 40 D12_OD2 41 D13_OD3 42 D17_OD7 43 sM1 44 sOUT 45 sINP 46 sMEMR 47 sHLTA 48 CLOCK 49 0_V2 50 +8_V 51 -16_V 52 0_V3 53 SLAVE_CLR* 54 TMA0* 55 TMA1* 56 TMA2* 57 sXTRQ* 58 A19 59 SIXTN* 60 A20 61 A21 62 A22 63 A23 64 NDEF2 65 NDEF3 66 PHANTOM* 67 MWRT 68 RFU3 69 0_V4 70 RFU4 71 RDY 72 INT* 73 HOLD* 74 RESET* 75 pSYNC 76 pWR* 77 pDBIN 78 A0 79 A1 80 A2 81 A6 82 A7 83 A8 84 A13 85 A14 86 A11 87 DO2_ED2 88 DO3_ED3 89 DO7_ED7 90 DI4_OD4 91 DI5_OD5 92 DI6_OD6 93 DI1_OD1 94 DI1_OD1 95 sINTA 96 sWO* 97 ERROR* 98 POC* 99 0_V5 100 P1

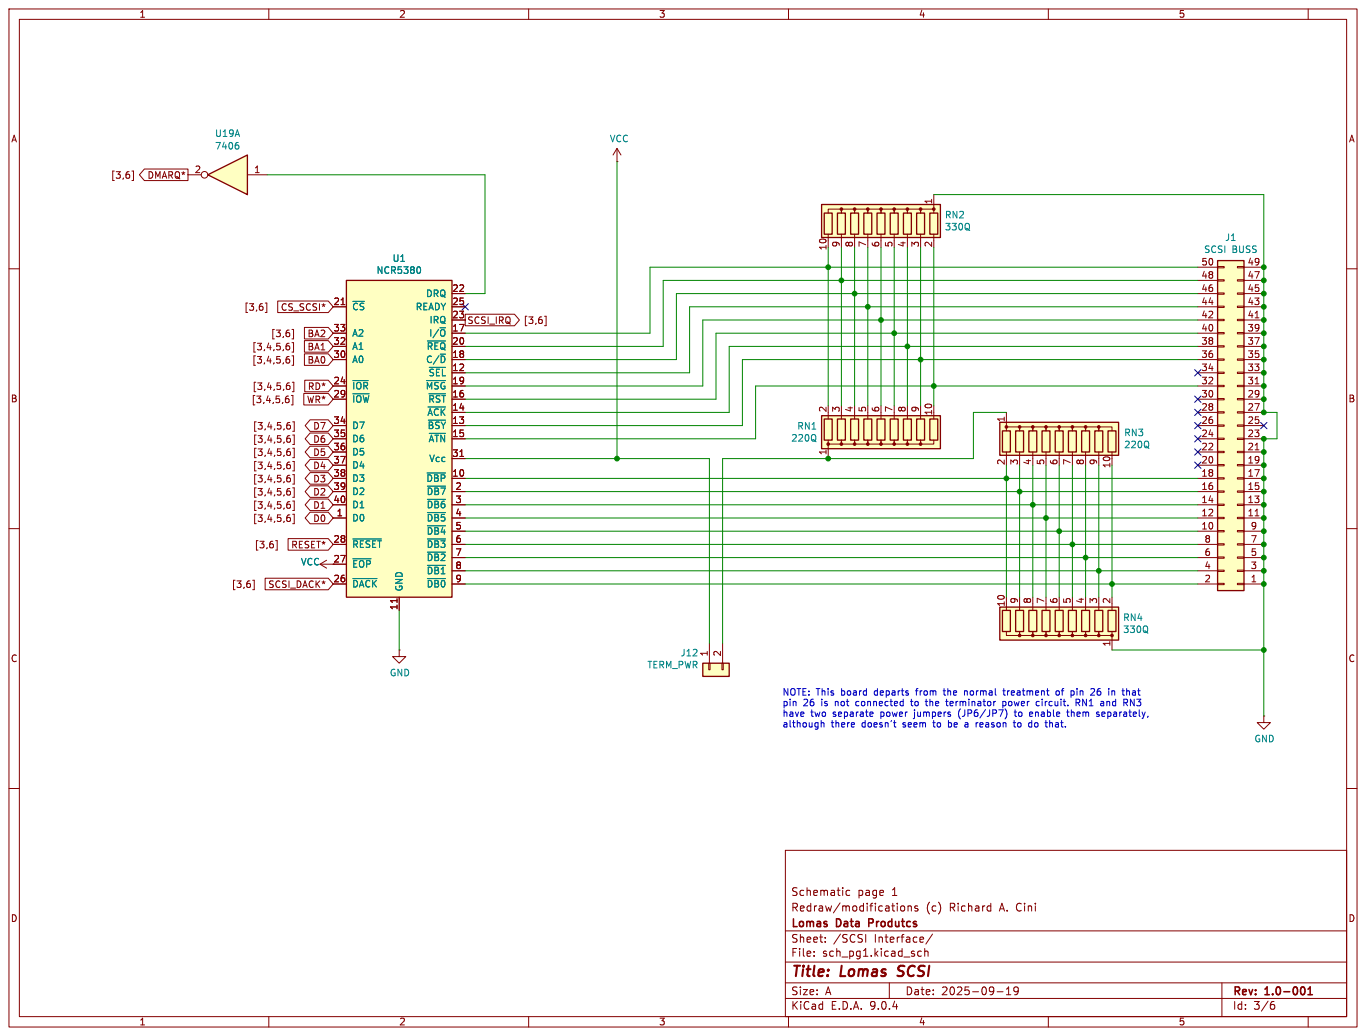
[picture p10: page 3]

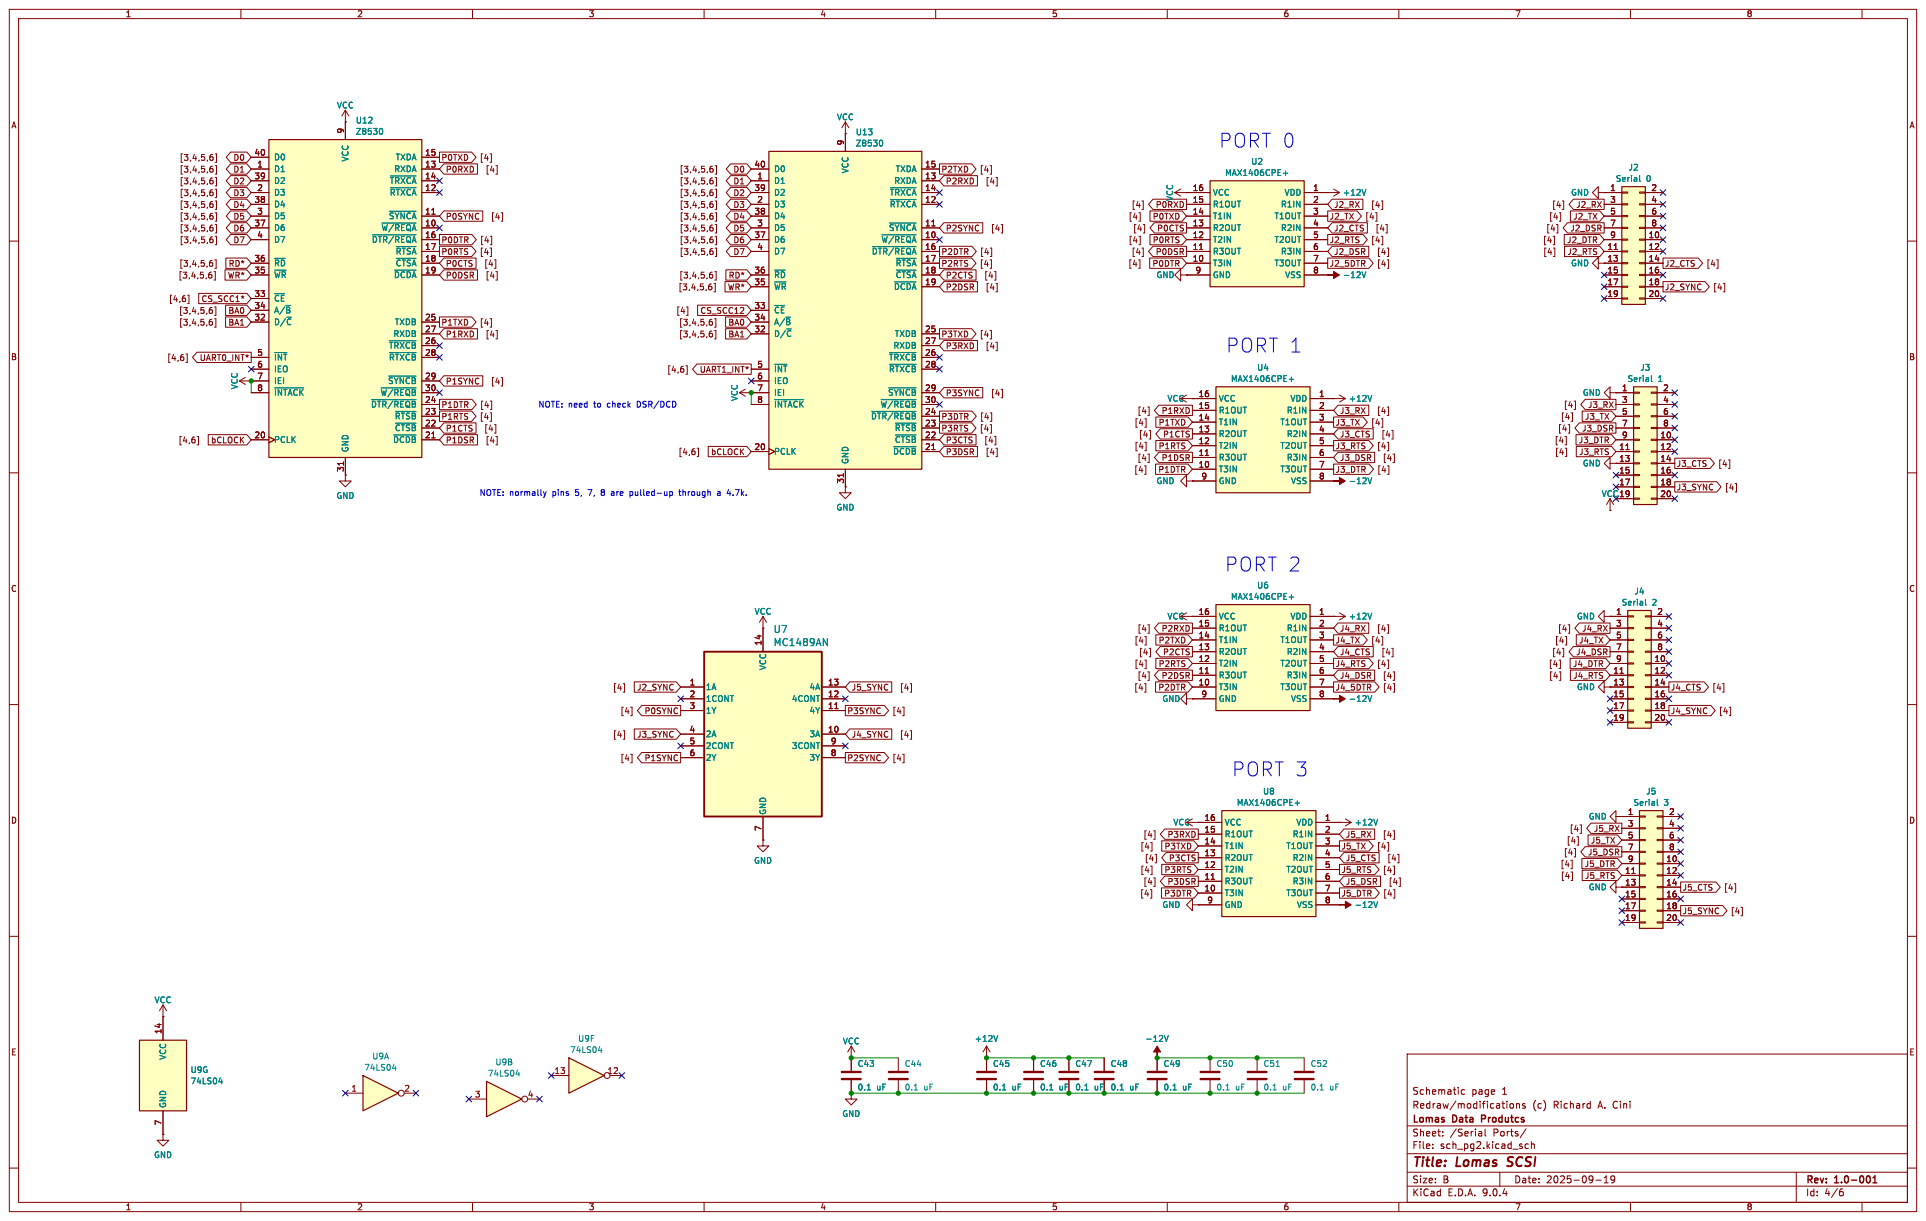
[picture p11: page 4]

9 GND 31 TXDA 15 RXDA 13 ~{TRXCA}14 ~{RTXCA}12 ~{SYNCA}11 ~{W/REQA}10 ~{DTR/REQA}16 ~{RTSA}17 ~{CTSA}18 ~{DCDA}19 TXDB 25 RXDB 27 ~{TRXCB}26 ~{RTXCB}28 ~{SYNCB}29 ~{W/REQB}30 ~{DTR/REQB} 24 ~{RTSB}23 ~{CTSB}22 ~{DCDB}21 VCC VCC VCC

9 GND 31 TXDA 15 RXDA 13 ~{TRXCA}14 ~{RTXCA}12 ~{SYNCA}11 ~{W/REQA}10 ~{DTR/REQA}16 ~{RTSA}17 ~{CTSA}18 ~{DCDA}19 TXDB 25 RXDB 27 ~{TRXCB}26 ~{RTXCB}28 ~{SYNCB}29 ~{W/REQB}30 ~{DTR/REQB} 24 ~{RTSB}23 ~{CTSB}22 ~{DCDB}21 VCC GND

9 GND 31 TXDA 15 RXDA 13 ~{TRXCA}14 ~{RTXCA}12 ~{SYNCA}11 ~{W/REQA}10 ~{DTR/REQA}16 ~{RTSA}17 ~{CTSA}18 ~{DCDA}19 TXDB 25 RXDB 27 ~{TRXCB}26 ~{RTXCB}28 ~{SYNCB}29 ~{W/REQB}30 ~{DTR/REQB} 24 ~{RTSB}23 ~{CTSB}22 ~{DCDB}21 U12 Z8530

9 GND 31 TXDA 15 RXDA 13 ~{TRXCA}14 ~{RTXCA}12 ~{SYNCA}11 ~{W/REQA}10 ~{DTR/REQA}16 ~{RTSA}17 ~{CTSA}18 ~{DCDA}19 TXDB 25 RXDB 27 ~{TRXCB}26 ~{RTXCB}28 ~{SYNCB}29 ~{W/REQB}30 ~{DTR/REQB} 24 ~{RTSB}23 ~{CTSB}22 ~{DCDB}21 U13 Z8530 GND

NOTE: need to check DSR/DCD

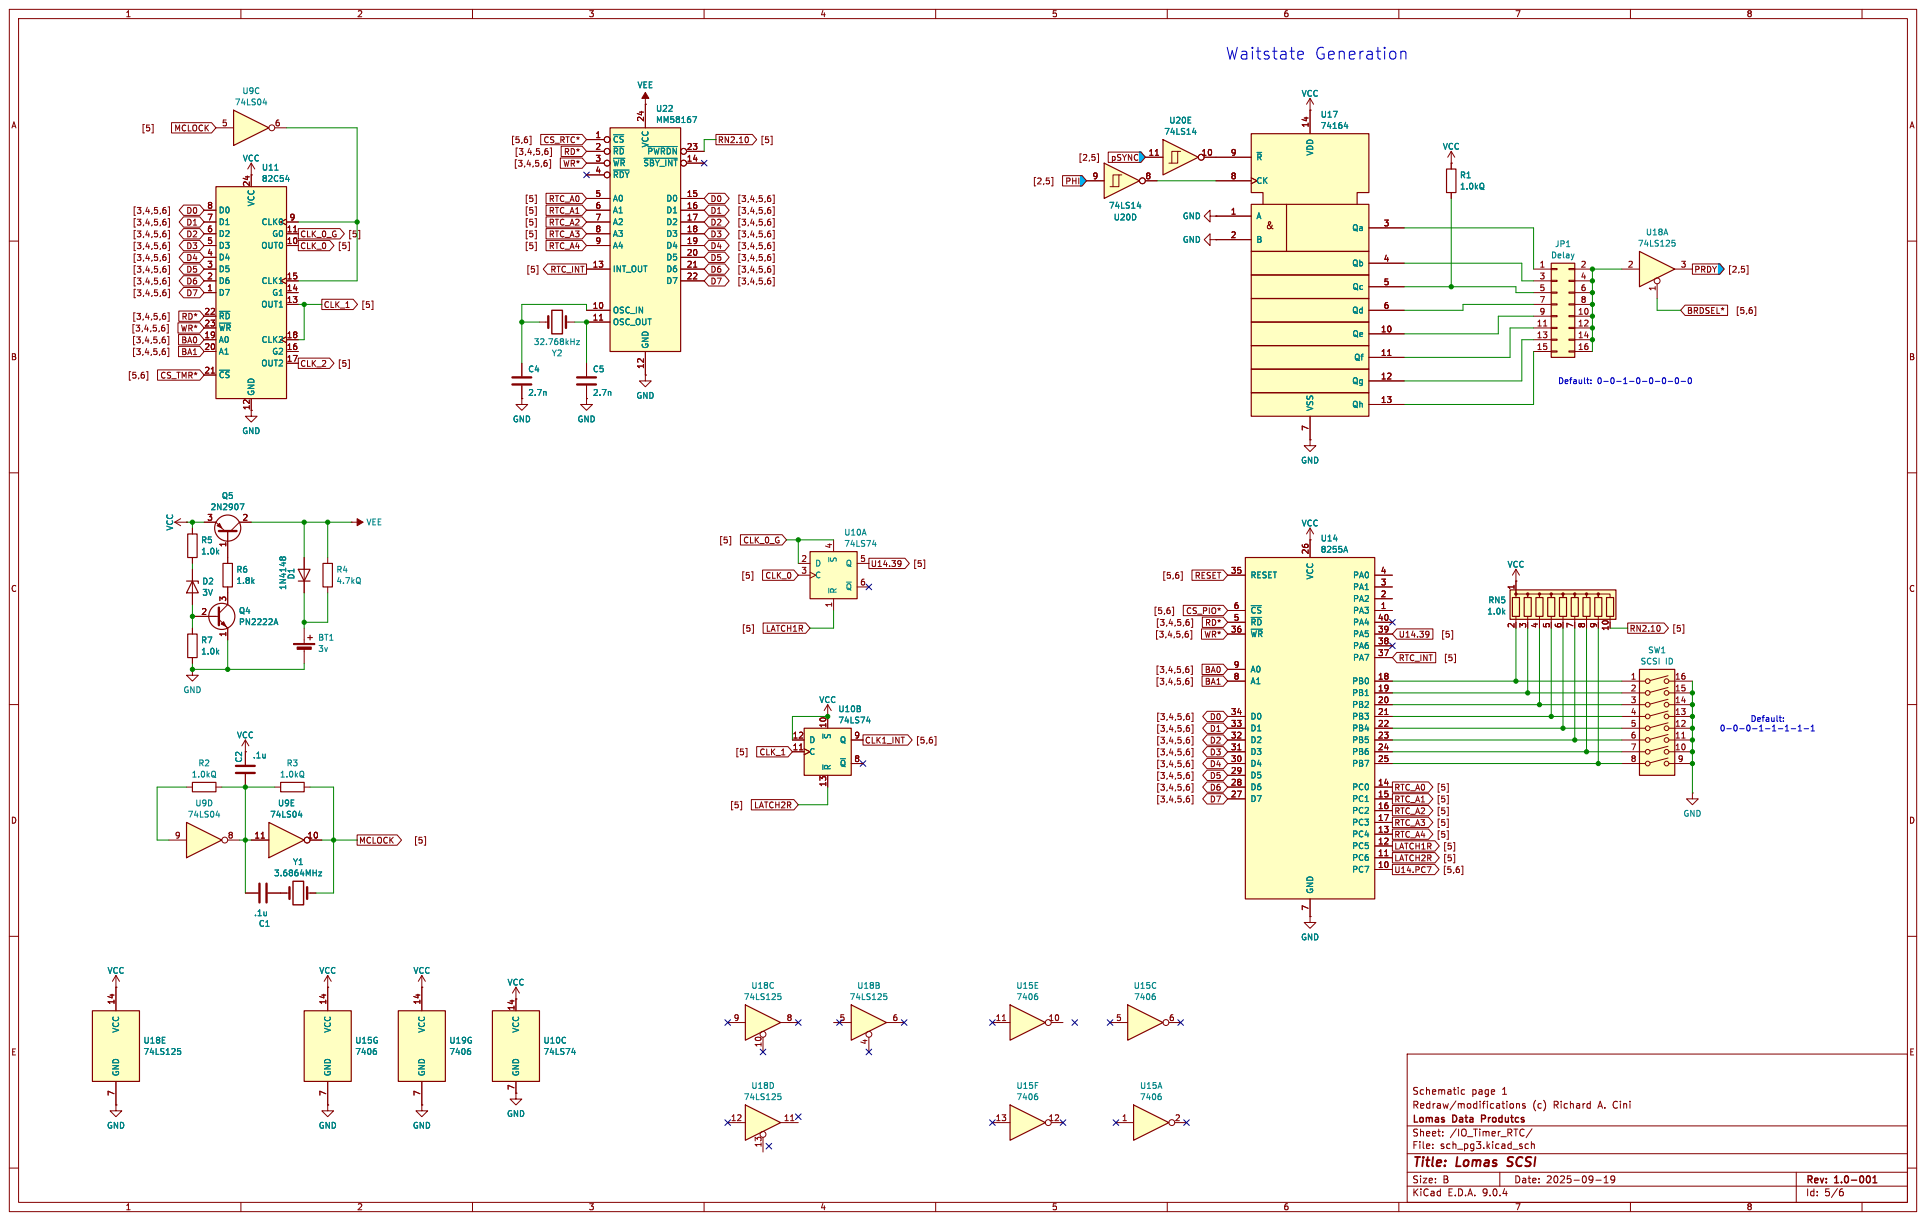
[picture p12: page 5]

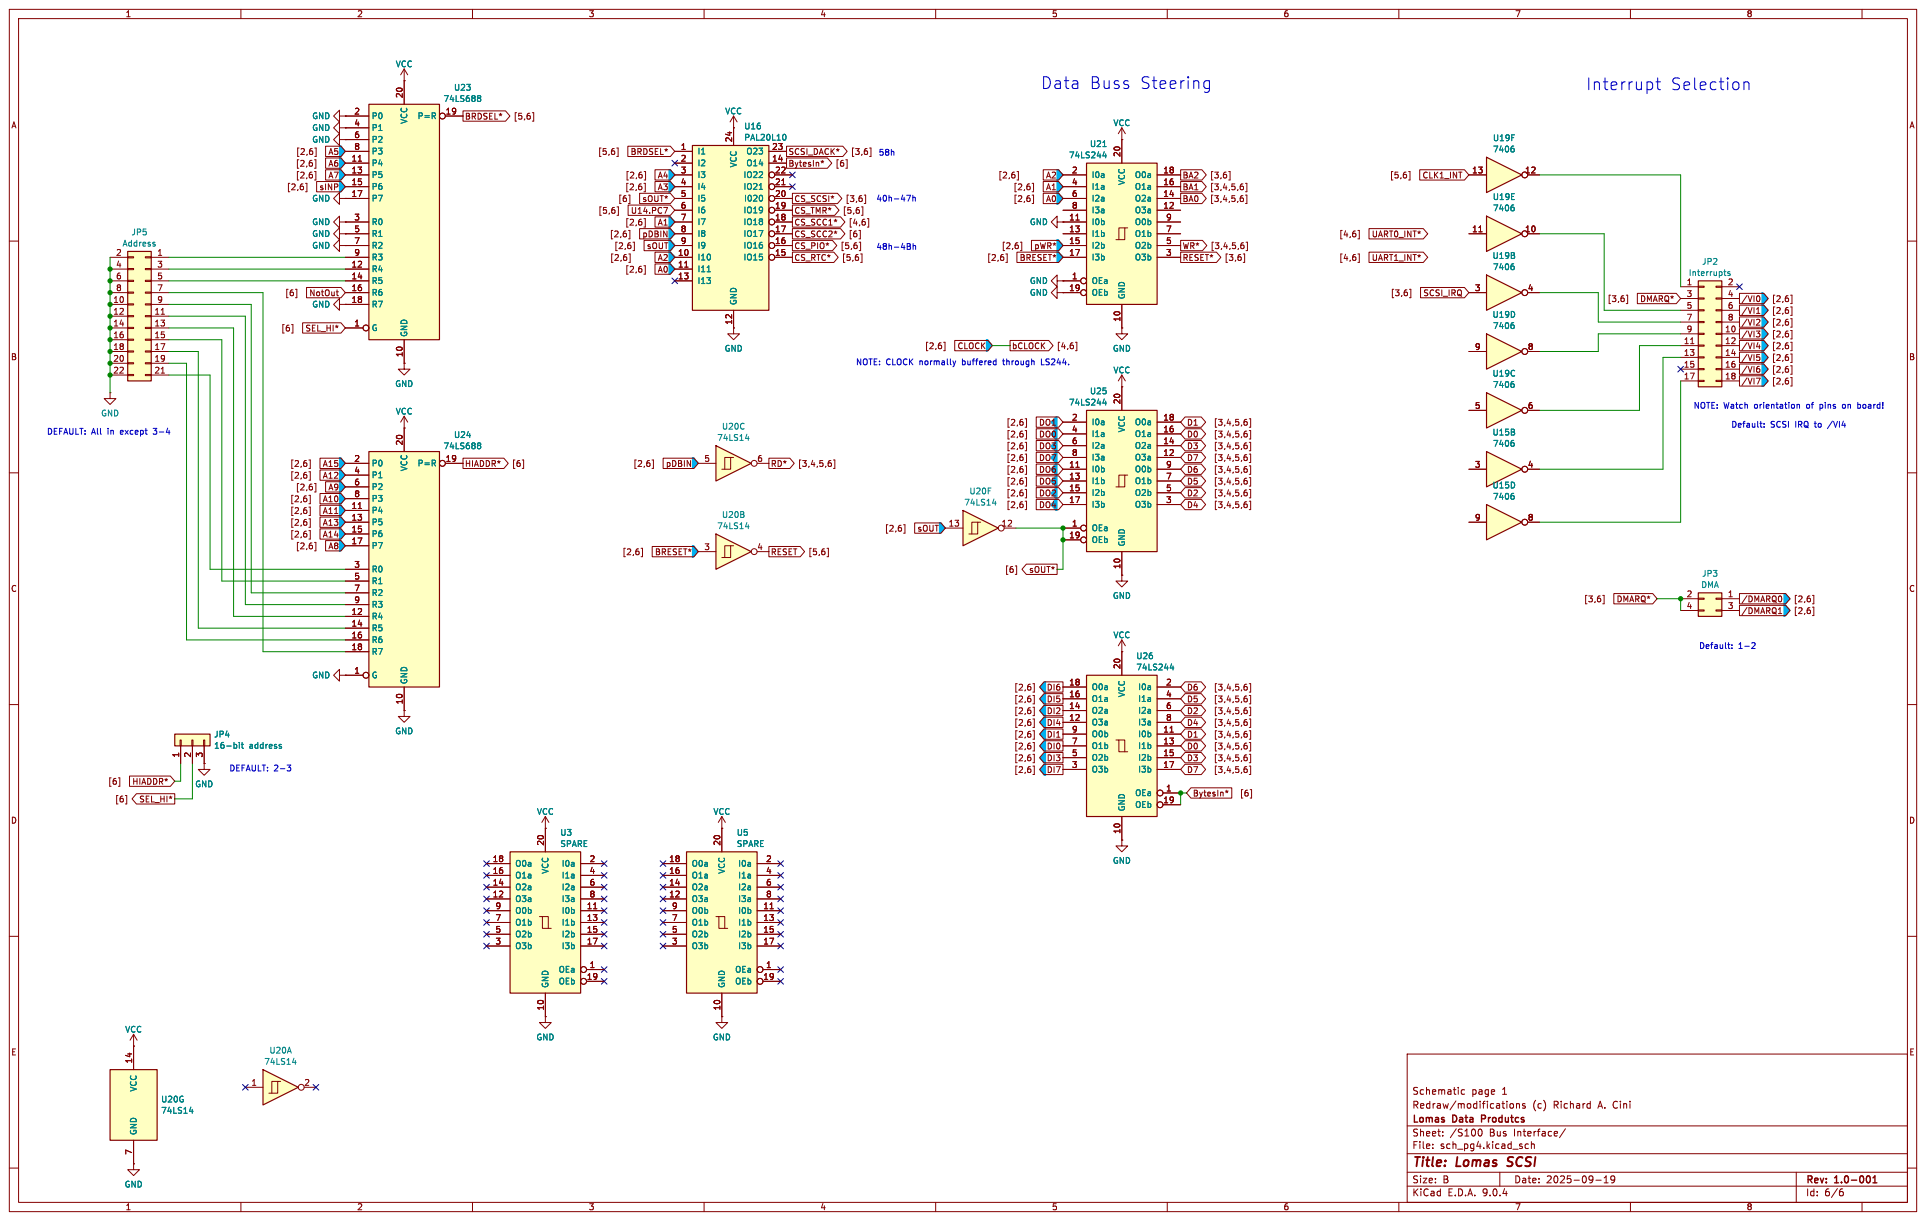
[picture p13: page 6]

74LS688 VCC GND GND GND GND
GND GND

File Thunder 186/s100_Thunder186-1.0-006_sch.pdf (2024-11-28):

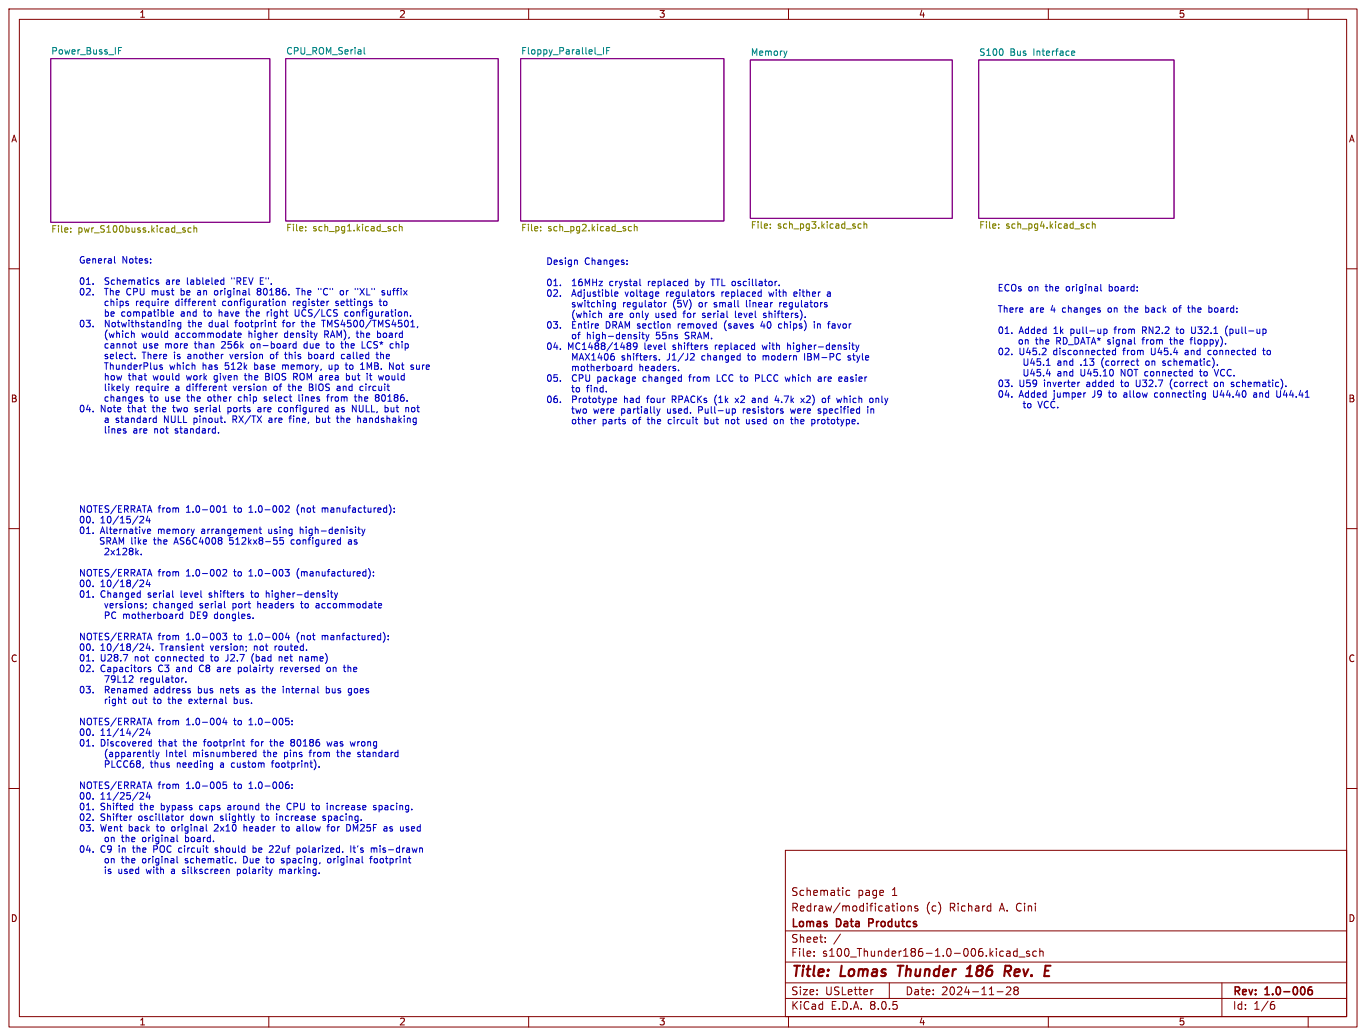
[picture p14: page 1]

Id: 1/6 Title: Lomas Thunder 186 Rev. E

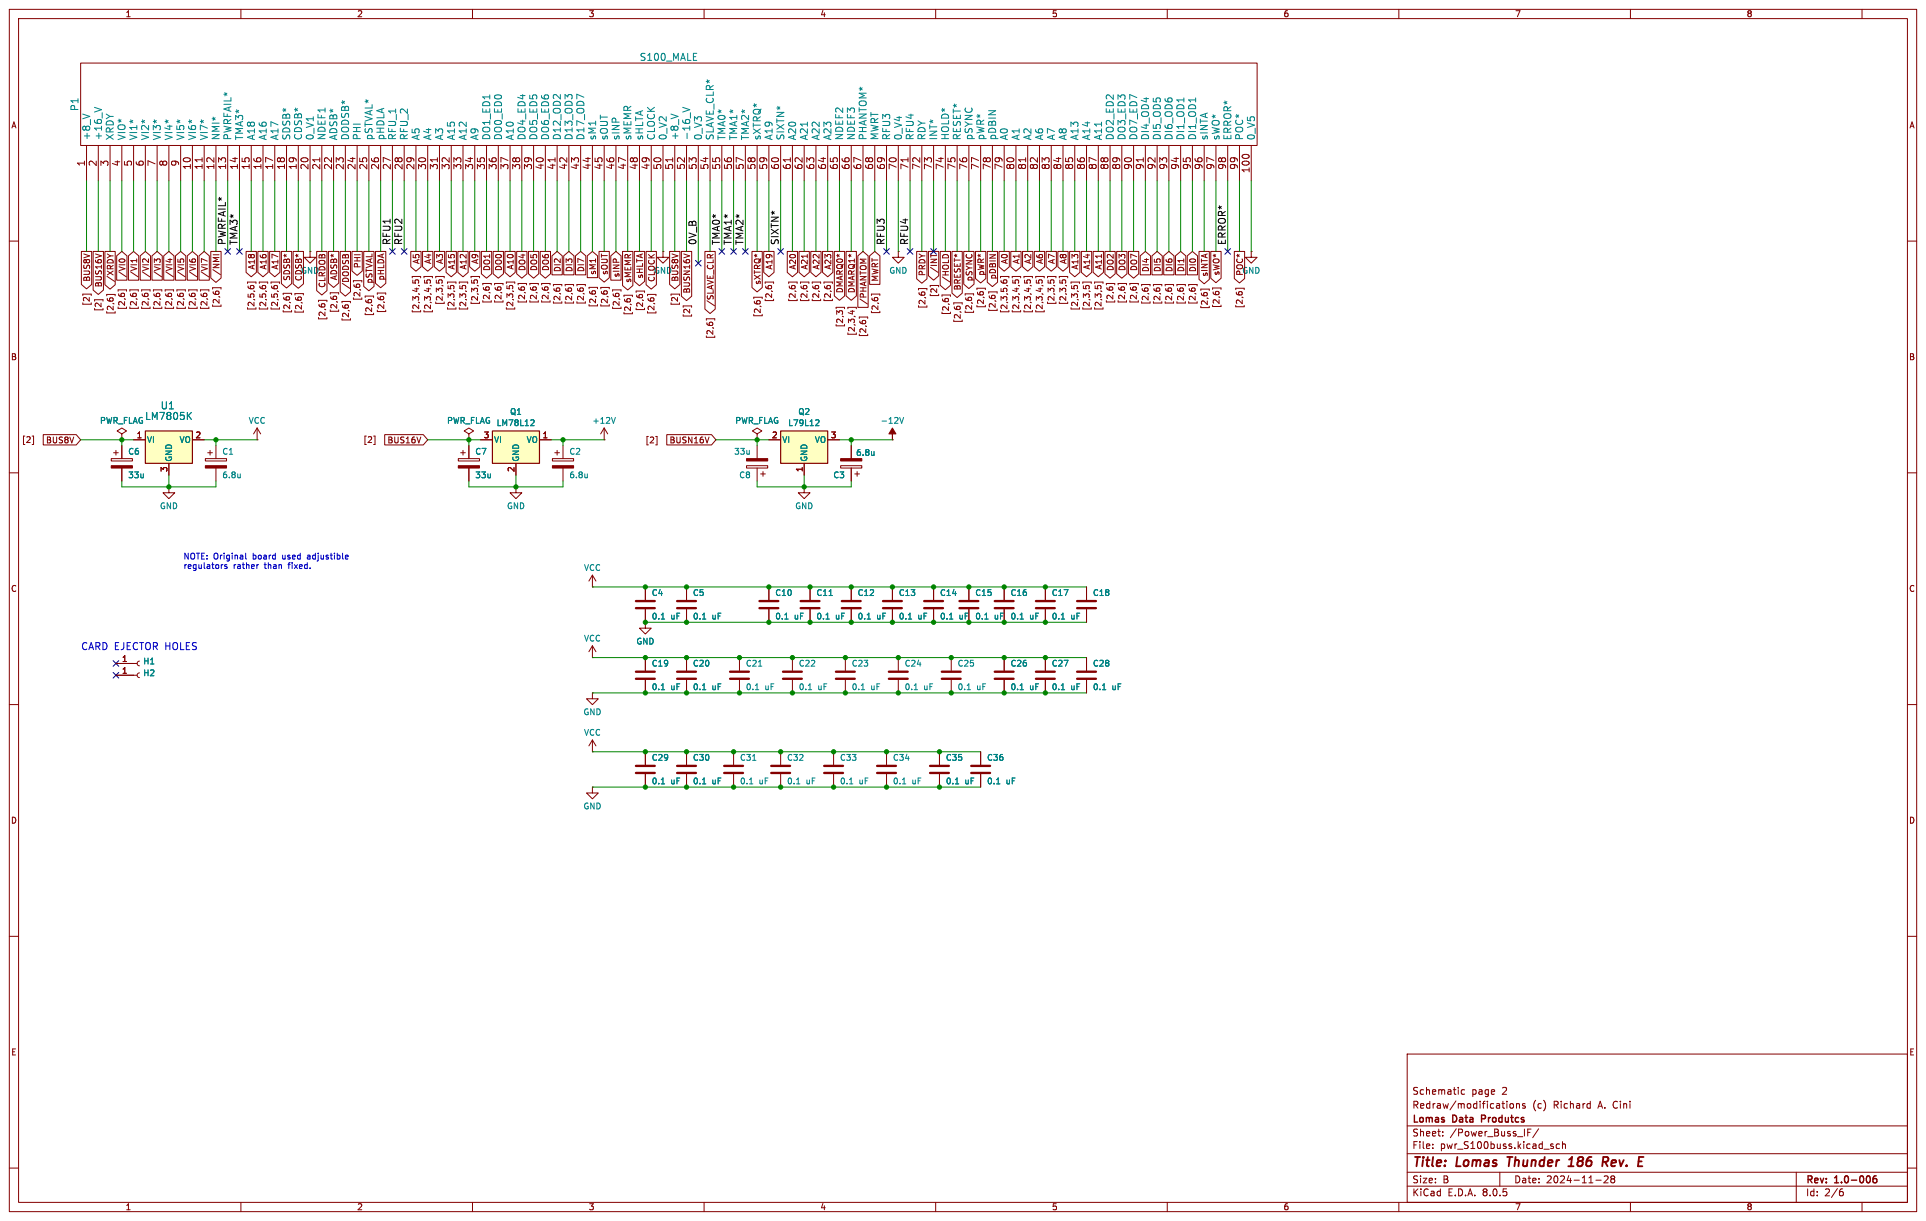
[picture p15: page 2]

3 A4 30 A3 31 A15 32 A12 33 A9 34 DO1_ED1 35 DO0_ED0 36 A10 37 DO4_ED4 38 DO5_ED5 39 VIO* 4 DO6_ED6 40 D12_OD2 41 D13_OD3 42 D17_OD7 43 sM1 44 sOUT 45 sINP 46 sMEMR 47 sHLTA 48 CLOCK 49 VI1* 5 0_V2 50 +8_V 51 -16_V 52 0_V3 53 SLAVE_CLR* 54 TMA0* 55 TMA1* 56 TMA2* 57 sXTRQ* 58 A19 59 VI2* 6 SIXTN* 60 A20 61 A21 62 A22 63 A23 64 NDEF2 65 NDEF3 66 PHANTOM* 67 MWRT 68 RFU3 69 VI3* 7 0_V4 70 RFU4 71 RDY 72 INT* 73 HOLD* 74 RESET* 75 pSYNC 76 pWR* 77 pDBIN 78 A0 79 VI4* 8 A1 80 A2 81 A6 82 A7 83 A8 84 A13 85 A14 86 A11 87 DO2_ED2 88 DO3_ED3 89 VI5* 9 DO7_ED7 90 DI4_OD4 91 DI5_OD5 92 DI6_OD6 93 DI1_OD1 94 DI1_OD1 95 sINTA 96 sWO* 97 ERROR* 98 POC* 99 P1

1 VI6* 10 0_V5 100 VI7* 11 NMI* 12 PWRFAIL* 13 TMA3* 14 A18 15 A16 16 A17 17 SDSB* 18 CDSB* 19 +16_V

2 0_V1 20 NDEF1 21 ADSB* 22 DODSB* 23 PHI 24 pSTVAL* 25 pHDLA 26 RFU_1 27 RFU_2 28 A5 29 XRDY

Id: 2/6 Title: Lomas Thunder 186 Rev. E

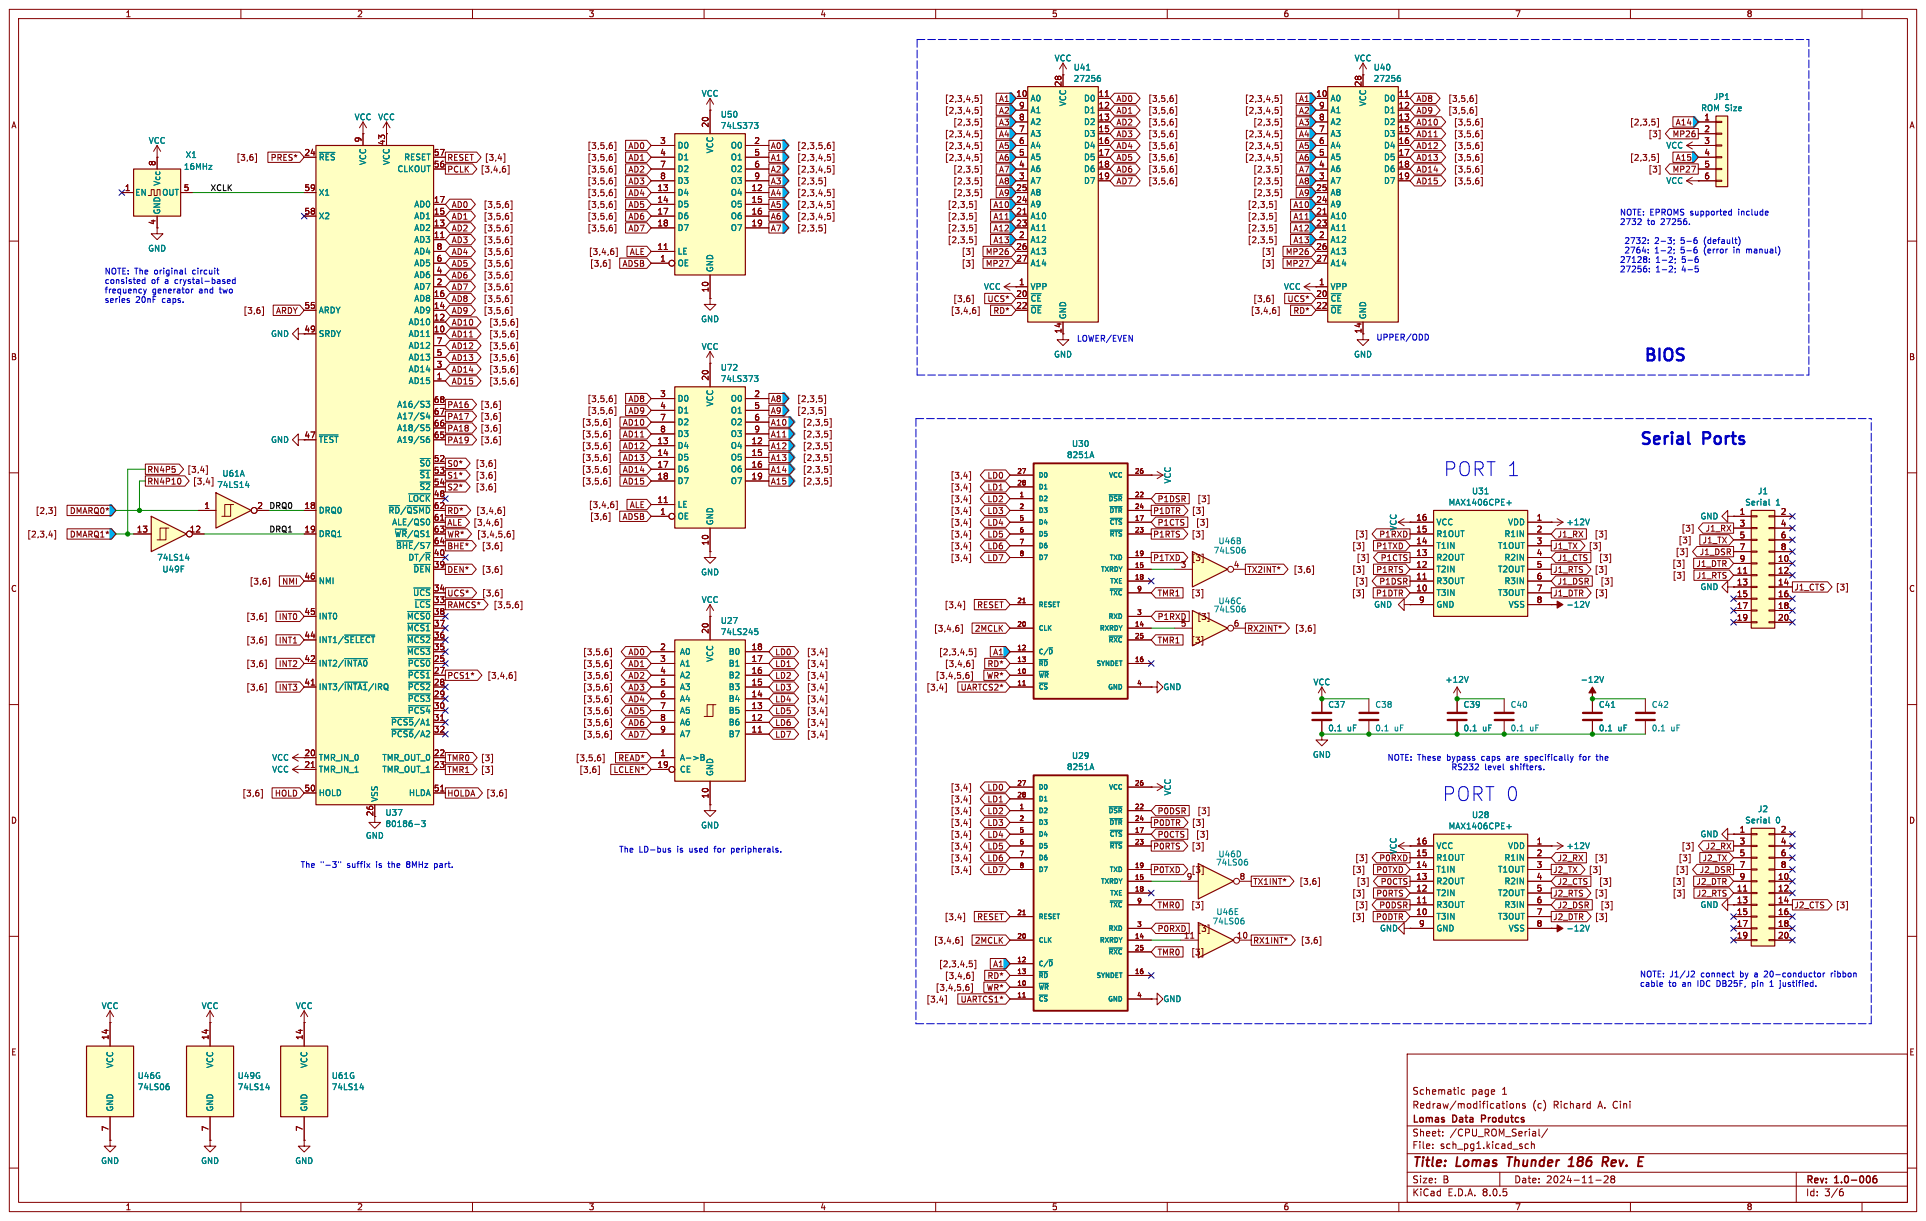
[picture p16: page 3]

VCC VCC GND VCC 14 GND
~{RES} 24

~{PCS1}27 ~{PCS2}28 ~{PCS3}29 AD14 3 ~{PCS4}30 ~{PCS5}/A131 ~{PCS6}/A232 ~{LCS} 33 ~{UCS} 34 ~{MCS3}35 ~{MCS2}36 ~{MCS1}37 ~{MCS0}38 ~{DEN} 39 AD6 4 DT/~{R}40

cable to an IDC DB25F, pin 1 justified.

Id: 3/6 Title: Lomas Thunder 186 Rev. E

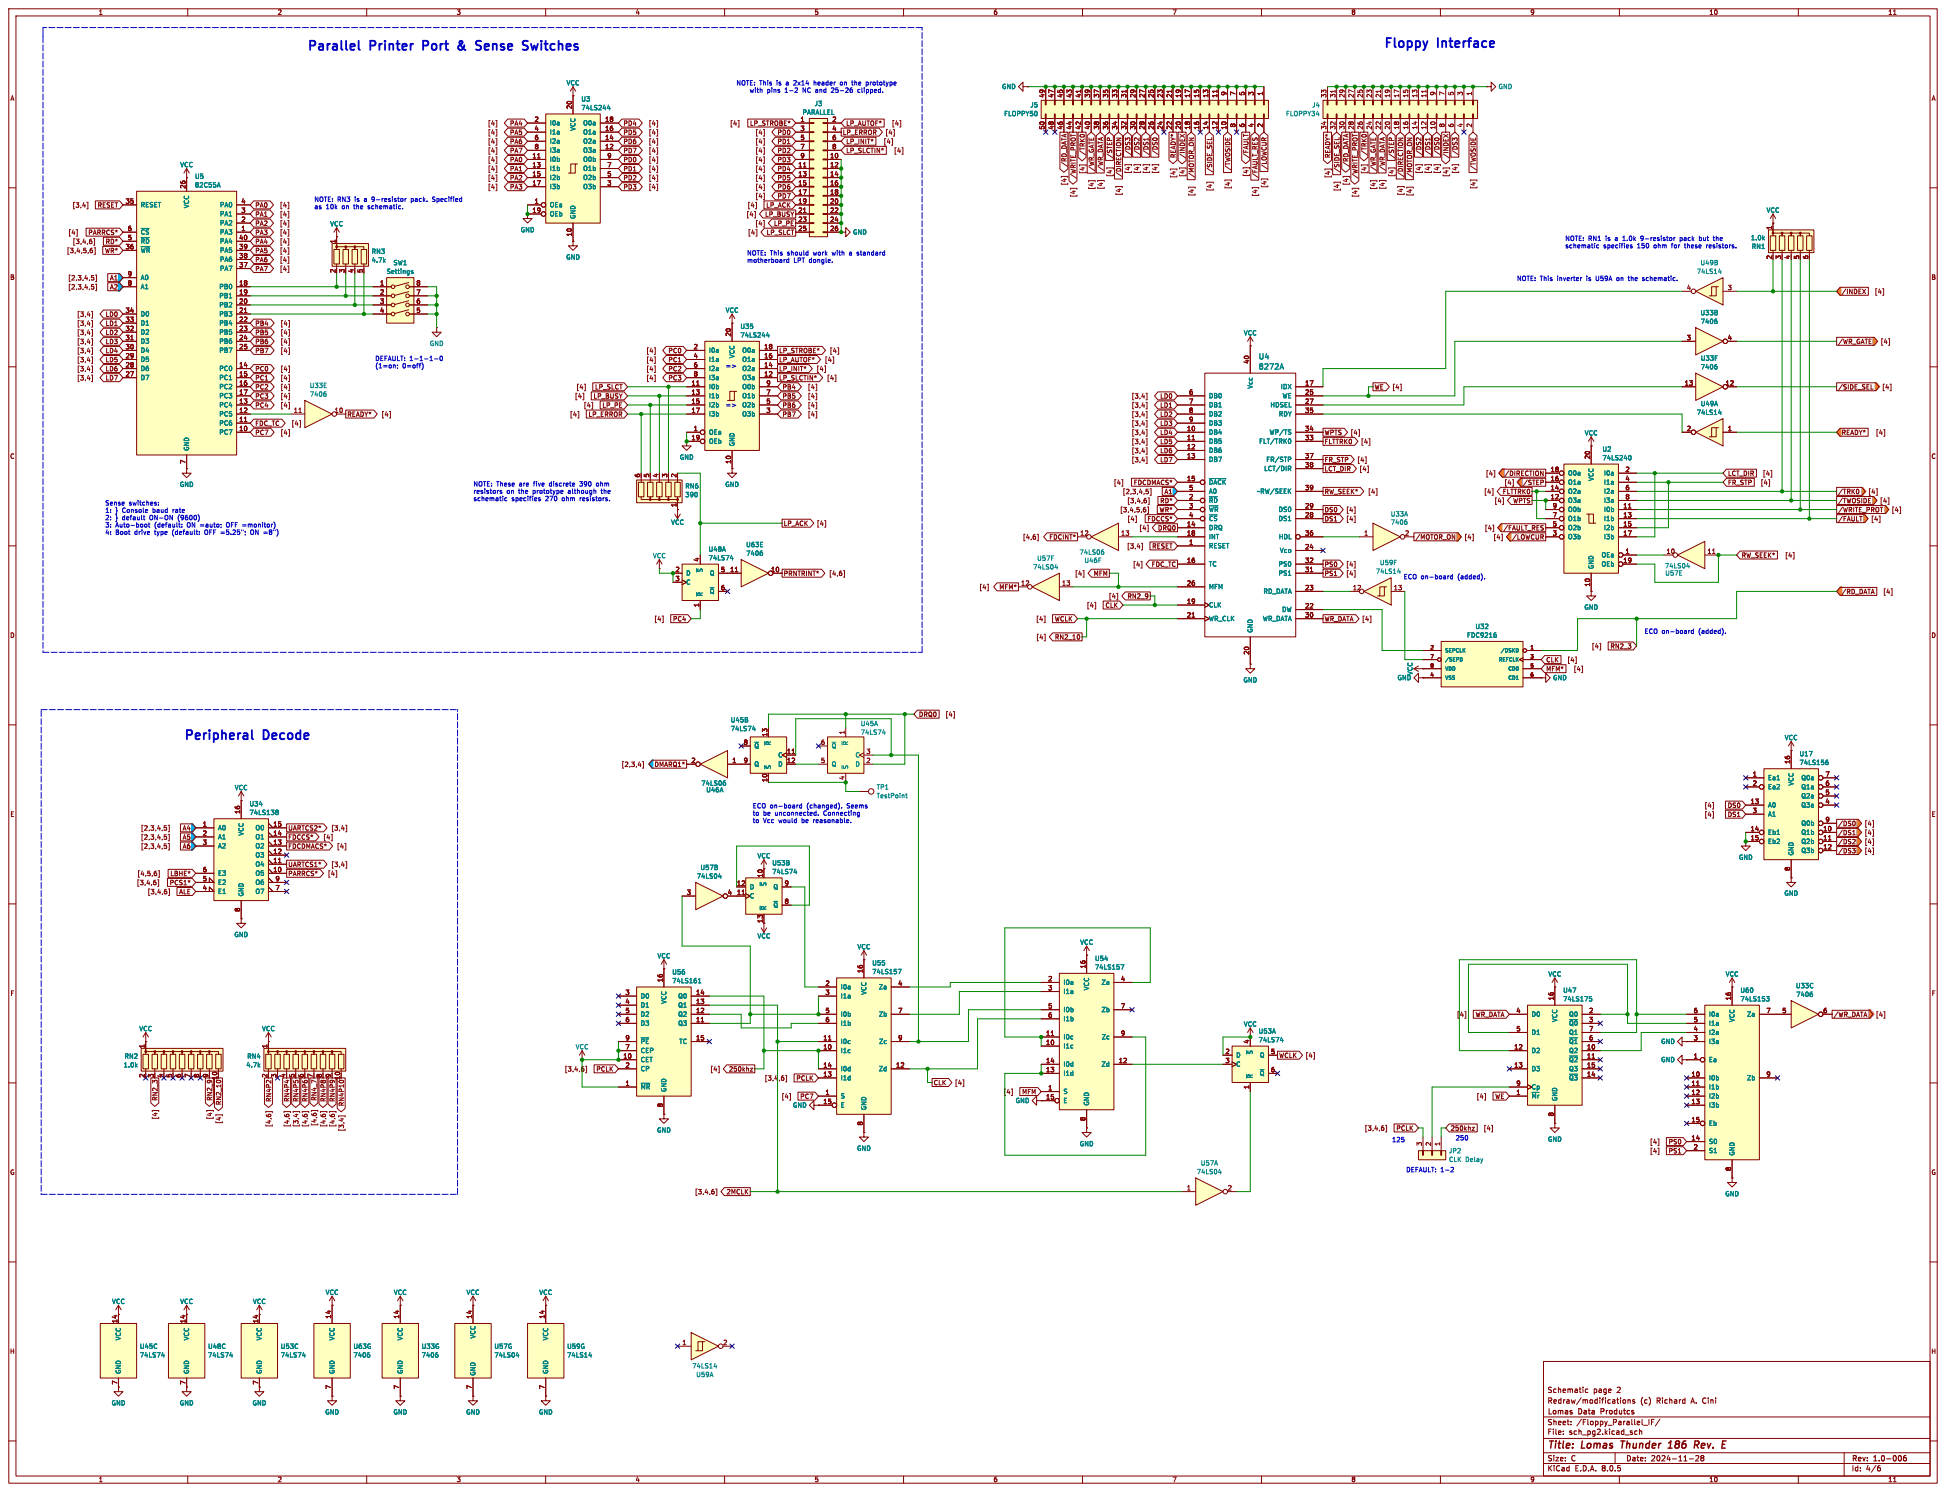
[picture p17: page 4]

to Vcc would be reasonable.

JP2 CLK Delay VCC GND
74LS157 GND

Id: 4/6 Title: Lomas Thunder 186 Rev. E

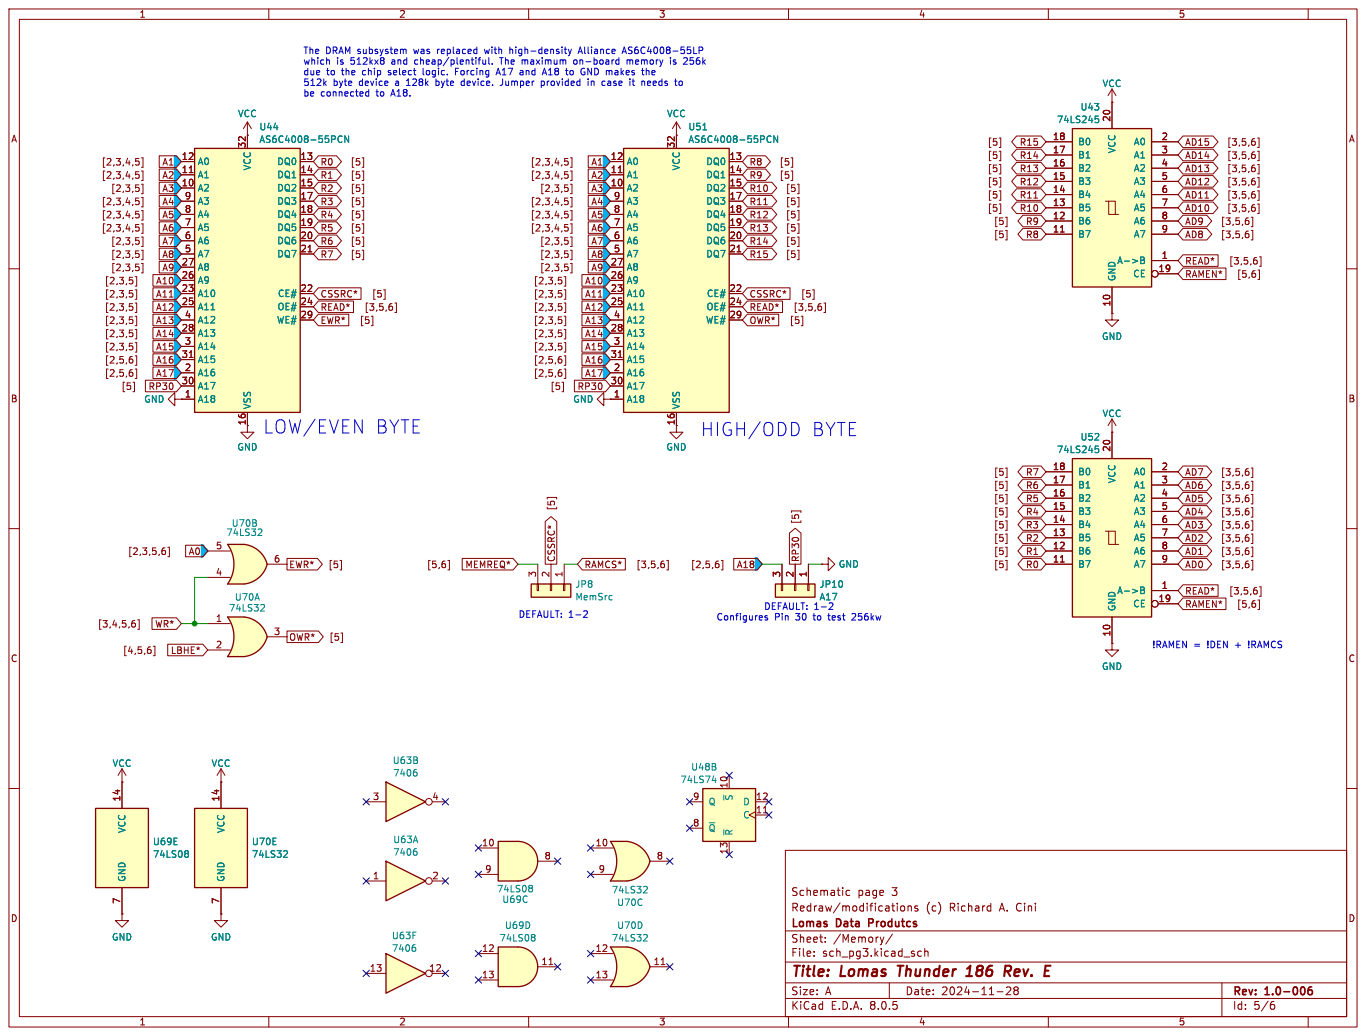
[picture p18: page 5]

512k byte device a 128k byte device. Jumper provided in case it needs to

!RAMEN = !DEN + !RAMCS GND

Id: 5/6 Title: Lomas Thunder 186 Rev. E

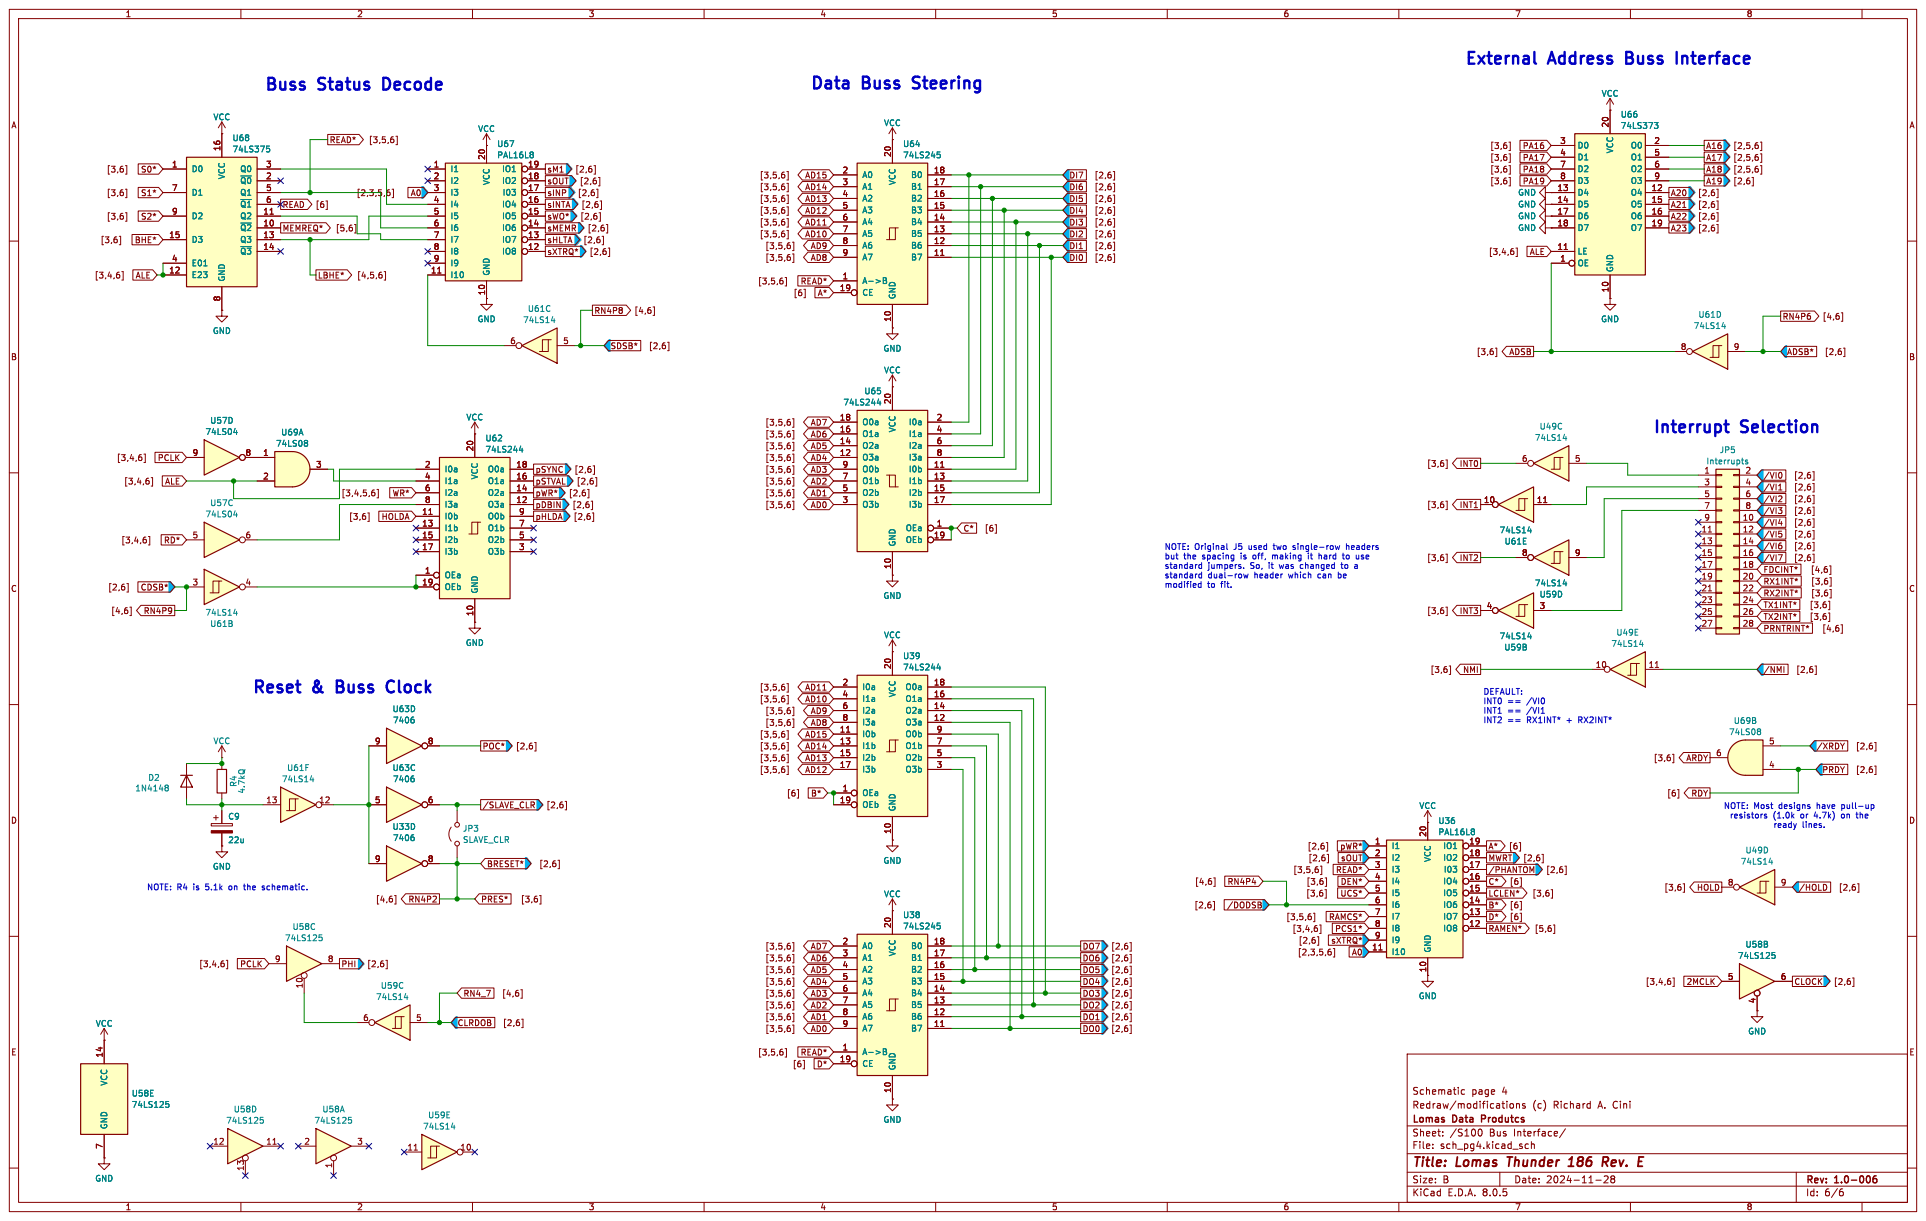
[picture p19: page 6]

External Address Buss Interface

ready lines. Data Buss Steering
NOTE: R4 is 5.1k on the schematic. Buss Status Decode
74LS375 VCC GND R4 4.7kQ

GND GND
GND

NOTE: Most designs have pull-up

Id: 6/6 Title: Lomas Thunder 186 Rev. E

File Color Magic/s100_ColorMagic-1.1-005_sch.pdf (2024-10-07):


IO Chips File: inout.kicad_sch Power_Buss_IF

the SCP 200B) generate that signal. Reused spare gate of the LS125

Id: 1/7 Title: Lomas Color Magic Redux


3 A4 30 A3 31 A15 32 A12 33 A9 34 DO1_ED1 35 DO0_ED0 36 A10 37 DO4_ED4 38 DO5_ED5 39 VIO* 4 DO6_ED6 40 D12_OD2 41 D13_OD3 42 D17_OD7 43 sM1 44 sOUT 45 sINP 46 sMEMR 47 sHLTA 48 CLOCK 49 VI1* 5 0_V2 50 +8_V 51 -16_V 52 0_V3 53 SLAVE_CLR* 54 TMA0* 55 TMA1* 56 TMA2* 57 sXTRQ* 58 A19 59 VI2* 6 SIXTN* 60 A20 61 A21 62 A22 63 A23 64 NDEF2 65 NDEF3 66 PHANTOM* 67 MWRT 68 RFU3 69 VI3* 7 0_V4 70 RFU4 71 RDY 72 INT* 73 HOLD* 74 RESET* 75 pSYNC 76 pWR* 77 pDBIN 78 A0 79 VI4* 8 A1 80 A2 81 A6 82 A7 83 A8 84 A13 85 A14 86 A11 87 DO2_ED2 88 DO3_ED3 89 VI5* 9 DO7_ED7 90 DI4_OD4 91 DI5_OD5 92 DI6_OD6 93 DI1_OD1 94 DI1_OD1 95 sINTA 96 sWO* 97 ERROR* 98 POC* 99 P1

1 VI6* 10 0_V5 100 VI7* 11 NMI* 12 PWRFAIL* 13 TMA3* 14 A18 15 A16 16 A17 17 SDSB* 18 CDSB* 19 +16_V

2 0_V1 20 NDEF1 21 ADSB* 22 DODSB* 23 PHI 24 pSTVAL* 25 pHDLA 26 RFU_1 27 RFU_2 28 A5 29 XRDY
0.1 uF GND

Id: 2/7 Title: Lomas Color Magic Redux


NOTE: Original used two stacked 6264 RAM chips in

Id: 3/7 Title: Lomas Color Magic Redux


to watch the usage. There was a 2764-based

8 Cp 9 VCC GND GND

Id: 4/7 Title: Lomas Color Magic Redux


10 | 9
12 | 11

14 | 13
16 | 15

to U64.10. TIE TO VCC. RN2

In the IBM CGA adapter, it's tied to Vcc. TIE TO VCC

Id: 5/7 Title: Lomas Color Magic Redux


J1 CGA Out VCC 14 GND

7 CP 8 ~{MR} 9 VCC GND

Id: 6/7 Title: Lomas Color Magic Redux


/TMRCS
74LS74 VCC 14 GND 7 VCC GND

NOTE: Board uses a 74125; LS family seems to work. SLAVE_CLR Enable: Some CPU cards do not generate SLAVE_CLR (like the SCP 200B) so this creates the

same signal for the bus. Jumper only if no other card provides this signal.

Id: 7/7 Title: Lomas Color Magic Redux

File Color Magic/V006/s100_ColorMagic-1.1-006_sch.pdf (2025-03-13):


IO Chips File: inout.kicad_sch Power_Buss_IF

the SCP 200B) generate that signal. Reused spare gate of the LS125

Id: 1/7 Title: Lomas Color Magic Redux


3 A4 30 A3 31 A15 32 A12 33 A9 34 DO1_ED1 35 DO0_ED0 36 A10 37 DO4_ED4 38 DO5_ED5 39 VIO* 4 DO6_ED6 40 D12_OD2 41 D13_OD3 42 D17_OD7 43 sM1 44 sOUT 45 sINP 46 sMEMR 47 sHLTA 48 CLOCK 49 VI1* 5 0_V2 50 +8_V 51 -16_V 52 0_V3 53 SLAVE_CLR* 54 TMA0* 55 TMA1* 56 TMA2* 57 sXTRQ* 58 A19 59 VI2* 6 SIXTN* 60 A20 61 A21 62 A22 63 A23 64 NDEF2 65 NDEF3 66 PHANTOM* 67 MWRT 68 RFU3 69 VI3* 7 0_V4 70 RFU4 71 RDY 72 INT* 73 HOLD* 74 RESET* 75 pSYNC 76 pWR* 77 pDBIN 78 A0 79 VI4* 8 A1 80 A2 81 A6 82 A7 83 A8 84 A13 85 A14 86 A11 87 DO2_ED2 88 DO3_ED3 89 VI5* 9 DO7_ED7 90 DI4_OD4 91 DI5_OD5 92 DI6_OD6 93 DI1_OD1 94 DI1_OD1 95 sINTA 96 sWO* 97 ERROR* 98 POC* 99 P1

1 VI6* 10 0_V5 100 VI7* 11 NMI* 12 PWRFAIL* 13 TMA3* 14 A18 15 A16 16 A17 17 SDSB* 18 CDSB* 19 +16_V

2 0_V1 20 NDEF1 21 ADSB* 22 DODSB* 23 PHI 24 pSTVAL* 25 pHDLA 26 RFU_1 27 RFU_2 28 A5 29 XRDY
0.1 uF GND

Id: 2/7 Title: Lomas Color Magic Redux


/EN4MD5 MD7 GA2 GA1 HCLK GA3 ODD: Attribute NOTE: Original used two stacked 6264 RAM chips in

Id: 3/7 Title: Lomas Color Magic Redux


to watch the usage. There was a 2764-based

8 Cp 9 VCC GND GND

Id: 4/7 Title: Lomas Color Magic Redux


10 | 9
12 | 11

14 | 13
16 | 15

to U64.10. TIE TO VCC. RN2

In the IBM CGA adapter, it's tied to Vcc. TIE TO VCC

Id: 5/7 Title: Lomas Color Magic Redux


J1 CGA Out VCC 14 GND

7 CP 8 ~{MR} 9 VCC GND

Id: 6/7 Title: Lomas Color Magic Redux


/TMRCS
74LS74 VCC 14 GND 7 VCC GND

NOTE: Board uses a 74125; LS family seems to work. SLAVE_CLR Enable: Some CPU cards do not generate SLAVE_CLR (like the SCP 200B) so this creates the

same signal for the bus. Jumper only if no other card provides this signal.

Id: 7/7 Title: Lomas Color Magic Redux




























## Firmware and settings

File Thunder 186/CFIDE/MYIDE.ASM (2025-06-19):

;
; Test Program to interact with the CPM3 type BIOS for the S100Computers IDE intreface board
;==============================================================================
;
;	V1.7	3/1/2010	;Removed Z80 Code (so it can be translated to 8086 code later)
;	V2.0	1/23/2011	;Updated to accomidate two CF cards (Master/Slave) & better menu options
;				;note I still have more work to do with this but what is here seem OK.
;	V2.1	2/5/2011	;Menu driven, and added code to copy & restore disk data from another
				;"backup" partition on disk
;	V2.2	2/13/2011	;Added Sec++ & Sec--
;	V2.3	2/15/2011	;Re-did drive initilization (Pulse CF cards twice on reset line)
;	V2.4	2/16/2011	;Correct small error for end of drive track check
;	V2.5	3/14/2011	;Added BOOT CPM option, cleaned up some areas.
;	V2.6	3/15/2011	;Re-dis reset line pulse. Correct CPM boot to Track 0 sector 1
;	V2.7	4/26/2011	;Add code for two drive system	
;	V2.8	4/27/2011	;Format sectors with E5's and warn "formatting CURRENT drive".
;	V2.9	3/28/2011	;Fixed initilization hanging if no drive present in drive #0 or #1 positions
;	V2.91	12/23/2017	;Fixed (double shifting) error in ZBITS


;Ports for 8255 chip. Change these to specify where your 8255 is addressed,
;The first three control which 8255 ports have the control signals,
;upper and lower data bytes.  The last one (IDEportCtrl), is for mode setting for the
;8255 to configure its actual I/O ports (A,B & C).  
;
;Note most drives these days dont use the old Head,Track, Sector terminology. Instead
;we use "Logical Block Addressing" or LBA. This is what we use below. LBA treats the drive
; as one continous set of sectors, 0,1,2,3,... 3124,....etc.  However as seen below we need to 
;convert this LBA to heads,tracks and sectors to be compatible with CPM & MSDOS.

;NOTE: If you have only one drive/CF card, be sure it is in drive #0 (LHS of board). The IDE hardware gets 
;confused if there is only a drive in slot #1.

	; INCLUDE Z-80 MACRO LIBRARY:
	MACLIB	Z80			;For the Z80 DJNZ opcode


IDEportA	EQU	030H	;Lower 8 bits of IDE interface (8255)
IDEportB	EQU	031H	;Upper 8 bits of IDE interface
IDEportC	EQU	032H	;Control lines for IDE interface
IDEportCtrl	EQU	033H	;8255 configuration port
IDEDrive	EQU	034H	;Bit 0 = 0 Drive A, =1 Drive B

READcfg8255	EQU	10010010b ;Set 8255 IDEportC to output, IDEportA/B input
WRITEcfg8255	EQU	10000000b ;Set all three 8255 ports to output mode

;IDE control lines for use with IDEportC.  

IDEa0line	EQU	01H	;direct from 8255 to IDE interface
IDEa1line	EQU	02H	;direct from 8255 to IDE interface
IDEa2line	EQU	04H	;direct from 8255 to IDE interface
IDEcs0line	EQU	08H	;inverter between 8255 and IDE interface
IDEcs1line	EQU	10H	;inverter between 8255 and IDE interface
IDEwrline	EQU	20H	;inverter between 8255 and IDE interface
IDErdline	EQU	40H	;inverter between 8255 and IDE interface
IDErstline	EQU	80H	;inverter between 8255 and IDE interface

;Symbolic constants for the IDE Drive registers, which makes the
;code more readable than always specifying the address bits

REGdata		EQU	IDEcs0line
REGerr		EQU	IDEcs0line + IDEa0line
REGseccnt	EQU	IDEcs0line + IDEa1line
REGsector	EQU	IDEcs0line + IDEa1line + IDEa0line
REGcylinderLSB	EQU	IDEcs0line + IDEa2line
REGcylinderMSB	EQU	IDEcs0line + IDEa2line + IDEa0line
REGshd		EQU	IDEcs0line + IDEa2line + IDEa1line		;(0EH)
REGcommand	EQU	IDEcs0line + IDEa2line + IDEa1line + IDEa0line	;(0FH)
REGstatus	EQU	IDEcs0line + IDEa2line + IDEa1line + IDEa0line
REGcontrol	EQU	IDEcs1line + IDEa2line + IDEa1line
REGastatus	EQU	IDEcs1line + IDEa2line + IDEa1line + IDEa0line

;IDE Command Constants.  These should never change.

COMMANDrecal	EQU	10H
COMMANDread	EQU	20H
COMMANDwrite	EQU	30H
COMMANDinit	EQU	91H
COMMANDid	EQU	0ECH
COMMANDspindown	EQU	0E0H
COMMANDspinup	EQU	0E1H


; IDE Status Register:
;  bit 7: Busy	1=busy, 0=not busy
;  bit 6: Ready 1=ready for command, 0=not ready yet
;  bit 5: DF	1=fault occured insIDE drive
;  bit 4: DSC	1=seek complete
;  bit 3: DRQ	1=data request ready, 0=not ready to xfer yet
;  bit 2: CORR	1=correctable error occured
;  bit 1: IDX	vendor specific
;  bit 0: ERR	1=error occured


				;Equates for display on SD Systems Video Board (Used In CPM Debugging mode only)
SCROLL		EQU	01H	;Set scrool direction UP.
LF		EQU	0AH
CR		EQU	0DH
BS		EQU	08H	;Back space (required for sector display)
BELL		EQU	07H
SPACE		EQU	20H
QUIT		EQU	11H	;Turns off any screen enhancements (flashing, underline etc).
NO$ENHANCEMENT	EQU	17H	;Turns off whatever is on
FAST		EQU	10H	;High speed scrool
TAB		EQU	09H	;TAB ACROSS (8 SPACES FOR SD-BOARD)
ESC		EQU	1BH
CLEAR		EQU	1CH	;SD Systems Video Board, Clear to EOL. (Use 80 spaces if EOL not available
				;on other video cards)
				
SEC$SIZE	EQU	512	;Assume sector size as 512. (Not tested for other sizes)
MAXSEC		EQU	3DH	;Sectors per track for CF my Memory drive, Kingston CF 8G. (For CPM format, 0-3CH)
				;This translates to LBA format of 1 to 3D sectors, for a total of 61 sectors/track.
				;This CF card actully has 3F sectors/track. Will use 3D for my CPM3 system because
				;my Seagate drive has 3D sectors/track. Don't want different CPM3.SYS files around
				;so this program as is will also work with a Seagate 6531 IDE drive

MAXTRK		EQU	0FFH	;CPM3 allows up to 8MG so 0-256 "tracks"
BUFFER$ORG	EQU	4000H	;<----- Will place all sector data here

CPM$BOOT$COUNT	EQU	12		;Allow up to 12 CPM sectors for CPMLDR
CPMLDR$ADDRESS	EQU	BUFFER$ORG	;We cannot load the CPMLDR at 100H in RAM since this is where this program resides

RDCON		EQU	1	;For CP/M I/O
WRCON		EQU	2
RESET$DISK	EQU	0DH	;Reset all CPM disks
PRINT		EQU	9
CONST		EQU	11	;CONSOLE STAT
BDOS		EQU	5

FALSE	EQU	0
TRUE	EQU	NOT FALSE

CPM		EQU	TRUE	;TRUE if output via CPM, FALSE if direct to hardware
DEBUG		EQU	TRUE
CPM$TRANSLATE	EQU	TRUE	;Translate Trk,Sec,Head to CPM TRACK# & SEC# on display



;--------------------------------------------------------------------------------------------
	ORG	100H		;<--- For CPM
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

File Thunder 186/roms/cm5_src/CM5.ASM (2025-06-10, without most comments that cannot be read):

TITLE LDP THUNDER REV 1.0 10/21/85 Color Magic ROM
PAGE  59,132

;option M510	; Assume MASM 5.1 if using MASM 6.11

;
; This is an IBM/PC-compatible BIOS ROM for installation in 
; the Thunder 186 single-board computer when used with the
; Color Magic CGA video board. By default, the Thunder 186
; comes with a conventional monitor ROM -- I would guess that
; this ROM was included with the purchase of the Color Magic,
; possibly as an extra-cost option since the Color Magic
; could be used in any other PC-capable S100 setup.
;

; NOTE: The Ampro LittleBoard 186 can boot from the SCSI channel
;	so this might be an option... 
; SCSI IRQ 3, port 310h, D8000h
;
; There is a system equates file referenced from the monitor and
; several hardware-specific files for initializing the 80186 and
; as the includes for the storage hardware. These have been 
; re-created.
;
; general items:
;	tmr0 = serial 0 clock
;	tmr1 = serial 1 clock
;	UCS = ROM @ FE000
;	LCS = 256k RAM
;	DRQ0 = bus DMA0
;	DRQ1 = floppy DRQ and bus DMA1
;	INT0 = bus VI0			} need to verify
;	INT1 = bus VI2/VI3		}
;	INT2 = bus VI4			}
;	INT3 = bus VI6/VI7 and RX1/RX2	}
;	NMI = parity fail (unused with SRAM) and bus NMI
;
;               masm cm5;              ( Assemble source code)
;               link cm5;              ( Link the object code)
;               debug cm5.EXE          ( Exe2bin  binary code)
;               -ncm5.BIN              ( Name of the output binary)
;;              -rBX                   ( Opens hi order byte count)
;;              :0                     (  ... must be 0 bytes long)
;;              -rCX                   ( Opens lo order byte count)
;;              :2000                  (  ... ROM is  2000 bytes long)
;;              -wCS:0	               ( Output to CM5.BIN file)
;;		-q
;
; I compiled a small program called chksum.exe using Visual C/C++ 1.52 running on
; Windows 3.1, based on an example I found on-line. It's a simple two's-compliment
; checksum. You need to run this on the CM5.BIN file otherwise it will checksum
; the MZ header as well. You can use a file/hex editor to patch it. If unaltered, 
; the checksum byte should be:
;
;	NORMAL: 	EDh
;	ROMSEARCH:	??h
;
; It seems that the code does test the checksum byte, but proceeds even if the
; checksum is bad, unlike the PC which will halt on a bad checksum.
;
;===============================================================================

FALSE		equ	0
TRUE		equ	0ffh
LF		equ	0Ah
CR		equ	0Dh

; System compilation options
DEBUGF		equ	TRUE		; allows marco expansion
ROMSEARCH	equ	FALSE		; set true to include expansion ROM search
SCSI		equ	FALSE		; SCSI configuration enabled

IF	SCSI
	scsi_options	equ	00100000b	;indicate that SCSI is present
ELSE
	scsi_options	equ	00000000b	;indicate no SCSI is present
ENDIF

entry   macro   x
        pad     =BANNER - $ + x	; - 0E000h
        if pad LT 0
        .err
        %out    'No room for ENTRY point'
        endif
        if pad GT 0
        db      pad DUP(0)
        endif
endm

jmpf    macro   x,y
        db      0EAh;
        dw      y,x
endm

;===============================================================================
;  Constants
include "T186.ASM"		; system equates
include "CM5D.ASM"		; ColorMagic-specific ports/data

Int00v		equ	0			; (0000:0000=0CA60h)  0 DIV/0
Int01v		equ	4			; (0000:0004=0F4h)    1 SST
Int06v		equ	18h			; (0000:0018=0CA60h)  6 invalid opcode
Int08v		equ	20h			; (0000:0020=0FEA5h)  8 Timer hardware IRQ
Int09v		equ	24h			; (0000:0024=0E987h)  9 Keyboard IRQ
Int0Bv		equ	2Ch			; (0000:002C=0CE80h) 0B serial 2 IRQ
Int0Cv		equ	30h			; (0000:0030=0CE80h) 0C serial 1 IRQ
Int0Dv		equ	34h			; (0000:0034=3ADBh)  0D hard disk IRQ
Int10v		equ	40h			; (0000:0040=0EEh)   10 video
Int11v		equ	44h			; (0000:0044=0CB20h) 11 equipment
Int12v		equ	48h			; (0000:0048=0CB40h) 12 memory size
Int13v		equ	4Ch			; (0000:004C=0CF60h) 13 diskette/HD I/O
Int14v		equ	50h			; (0000:0050=0CB80h) 14 serial
Int15v		equ	54h			; (0000:0054=0CBA0h) 15 system services
Int16v		equ	58h			; (0000:0058=0CFC0h) 16 keyboard
Int17v		equ	5Ch			; (0000:005C=0CBC0h) 17 printer
Int18v		equ	60h			; (0000:0060=0CD00h) 18 Basic ROM
Int19v		equ	64h			; (0000:0064=0CC60h) 19 IPL
Int1Av		equ	68h			; (0000:0068=0CBE0h) 1A TOD
Int1Bv		equ	6Ch			; (0000:006C=0D1C0h) 1B Keyboard BREAK addr
Int1Cv		equ	70h			; (0000:0070=0CC00h) 1C user timer
Int1Dv		equ	74h			; (0000:0074=0C958h) 1D 6845 video init
Int1Ev		equ	78h			; (0000:0078=0CA60h) 1E DPB
Int1Fv		equ	7Ch			; (0000:007C=5E9h)   1F video graphic table

IPLLOC		equ	7C00h			;*(0000:7C00=0)	boot location
data_49e	equ	0			;*(1000:0000=75h)
data_50e	equ	3FEh			;*(1040:03FE=3)	COM1 block? Count?
; Outside of ROM address; likely just 8K address increments
data_121e	equ	2000h			;*(A.2000=0)
data_122e	equ	2001h			;*(A.2001=0)

; The Lomas BIOS doesn't produce error codes, but these might be useful.
ER_BIOS equ     01h             ; Bad ROM bios checksum, patch last byte
ER_RAM  equ     02h             ; Bad RAM in main memory, replace
ER_CRT  equ     04h             ; Bad RAM in video card, replace
ER_MEM  equ     10h             ; Bad RAM in vector area, replace
ER_ROM  equ     20h             ; Bad ROM in expansion area, bad checksum


;===============================================================================
;  Compiler directives
;
ifndef DEBUGF
.SALL                                           ; Suppress Macro Expansions
endif
.LFCOND                                         ; List False Conditionals
.186
ASSUME  DS:data, SS:code, CS:code, ES:code
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

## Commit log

2023-05-09 Add files via upload
    Board PALs
2024-02-24 Add files via upload
    Updated to current version. Still plotting...
    [buffmem.kicad_sch, clockaddr.kicad_sch, inout.kicad_sch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]
2024-10-07 Add files via upload
    Final versions uploaded.
    [buffmem.kicad_sch, clockaddr.kicad_sch, inout.kicad_sch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]
2024-11-03 Add files via upload
    BOM created by Peter Higgins for the project.
    [Color Magic BOM.xlsx]
2024-11-25 Add files via upload
    Updated to final versions.
    [pwr_S100buss.kicad_sch, s100_Thunder186-1.0-006.kicad_sch, s100_Thunder186-1.0-006.xlsx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]
2025-06-19 Add files via upload
    Schematic based on ohming-out board. DO NOT MANUFACTURE.
2026-01-16 Update README.md with driver and video subsystem details
    Expanded on the slow boot configuration and screen anomaly details.
